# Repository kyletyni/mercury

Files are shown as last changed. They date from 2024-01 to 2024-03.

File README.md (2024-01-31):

This is a custom PCB and software design I created to compete in the APEC Micromouse 
competition in 2024. The design is based on the ESP32-S3 which is a dual core 
microprocessor. The pcb design was done in Kicad 7.0 and the MCU was programmed using 
the esp-idf utilizing RTOS for time dsensitive task scheduling.

Here is a link to an earlier hardware design running in a maze setting with 
control software:
<a href="https://www.youtube.com/watch?v=heloENtCQyA" target="_blank">Demo Video Link</a>

mouse demo (https://www.youtube.com/watch?v=heloENtCQyA)

The PCB schematic consists of IR emitters and receivers, power modules, the MCU, 
gyro, encoders, and buttons.
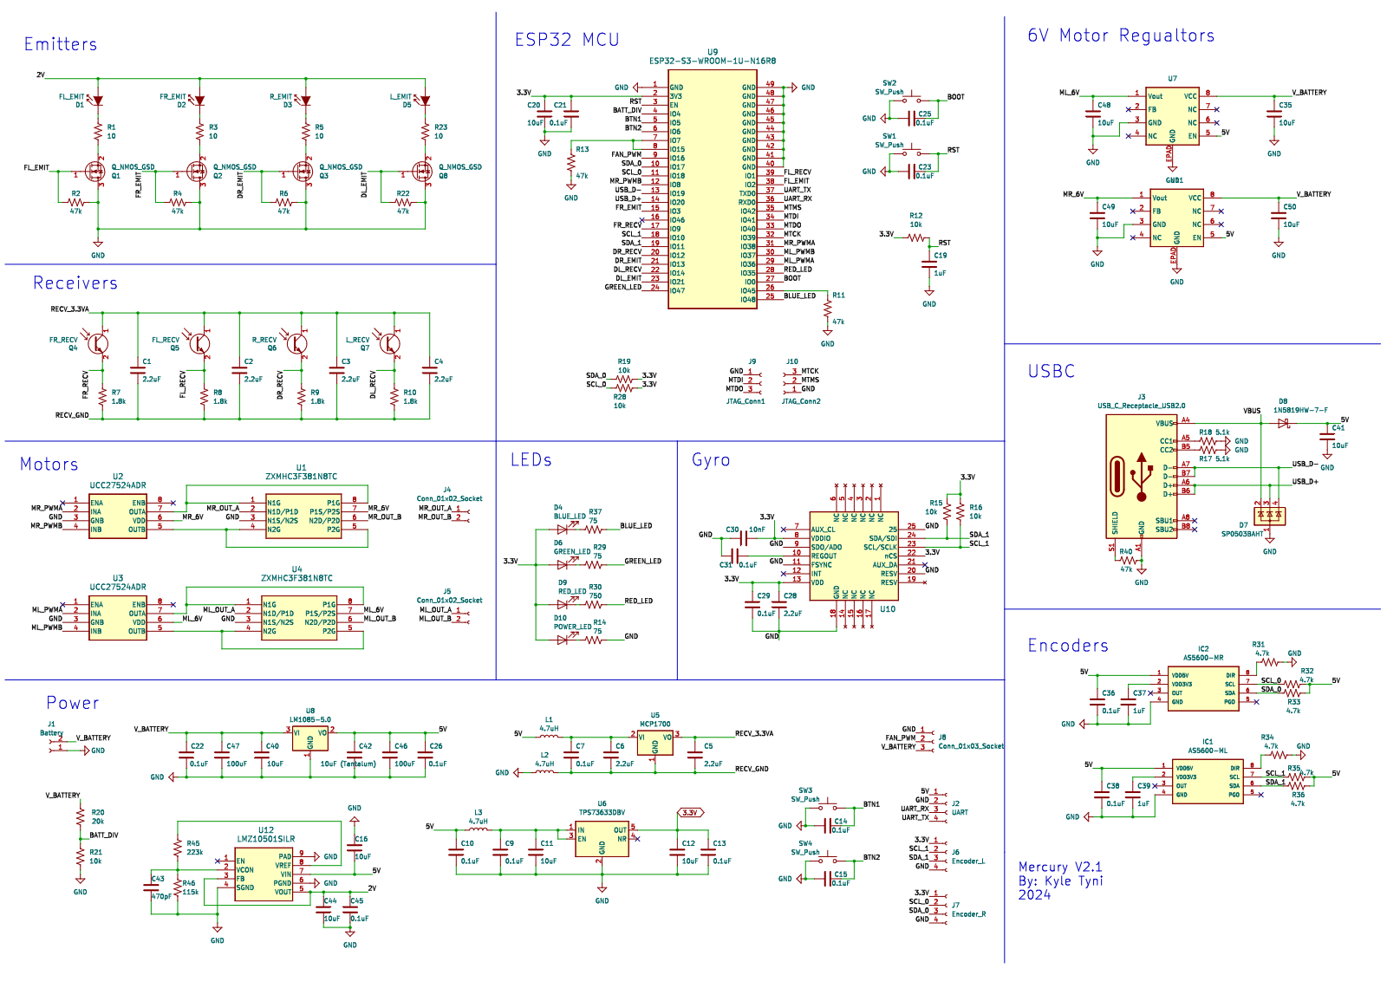
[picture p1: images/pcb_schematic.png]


This is what the PCB looked like when it was delivered.
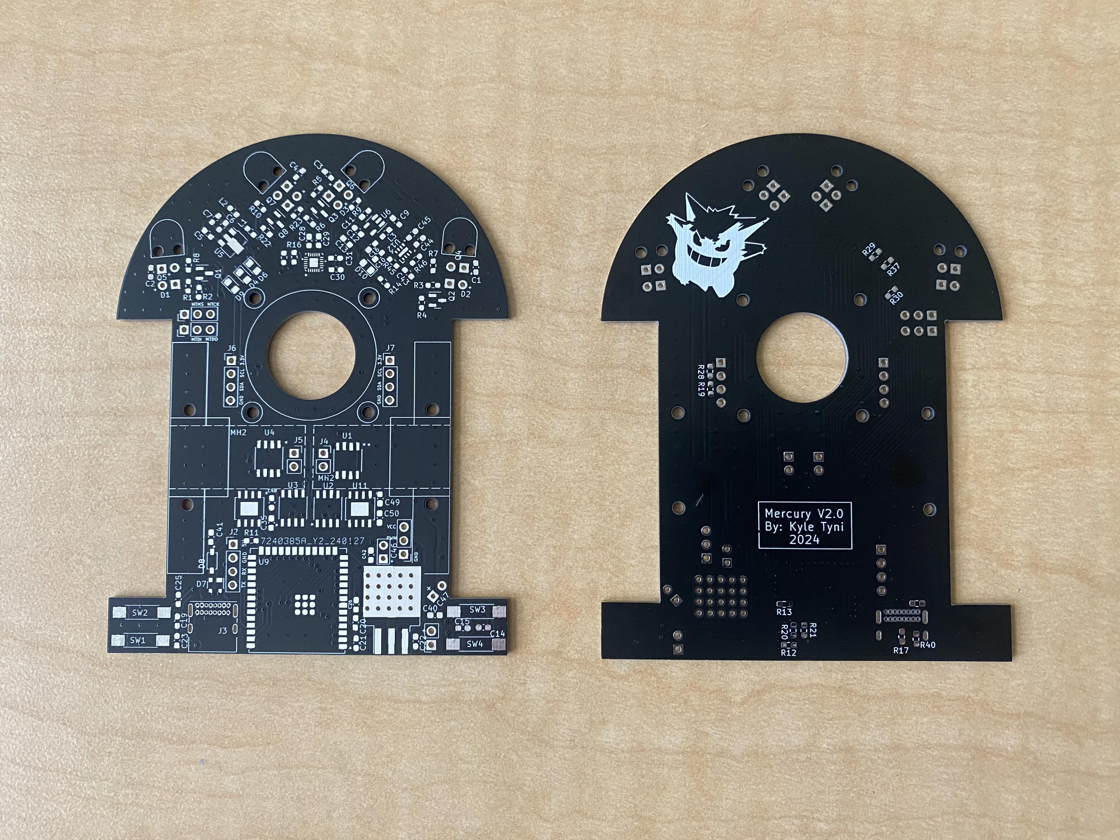
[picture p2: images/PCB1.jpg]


Assembly complete! Software is still a work in progress, but all modules on the board
function individually as expected.

<div style="display:flex; justify-content:space-between;">
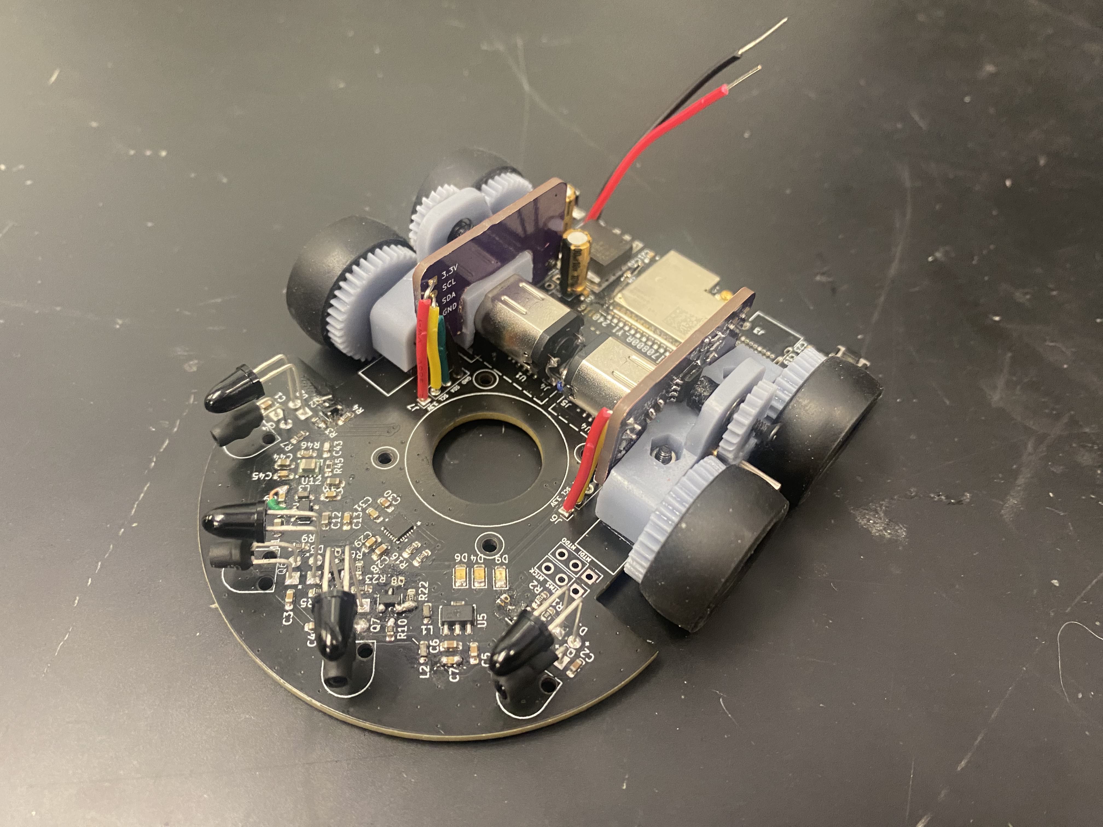
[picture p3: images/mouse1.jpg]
  
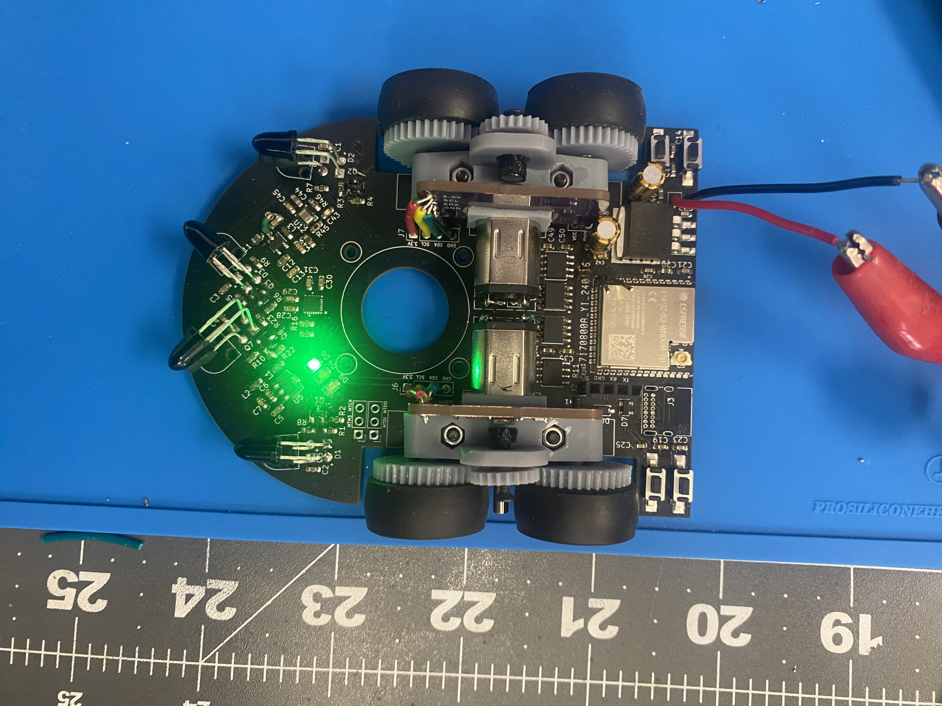
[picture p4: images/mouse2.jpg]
  
</div>

Layout of front and back layers of the board.
<div style="display:flex; justify-content:space-between;">
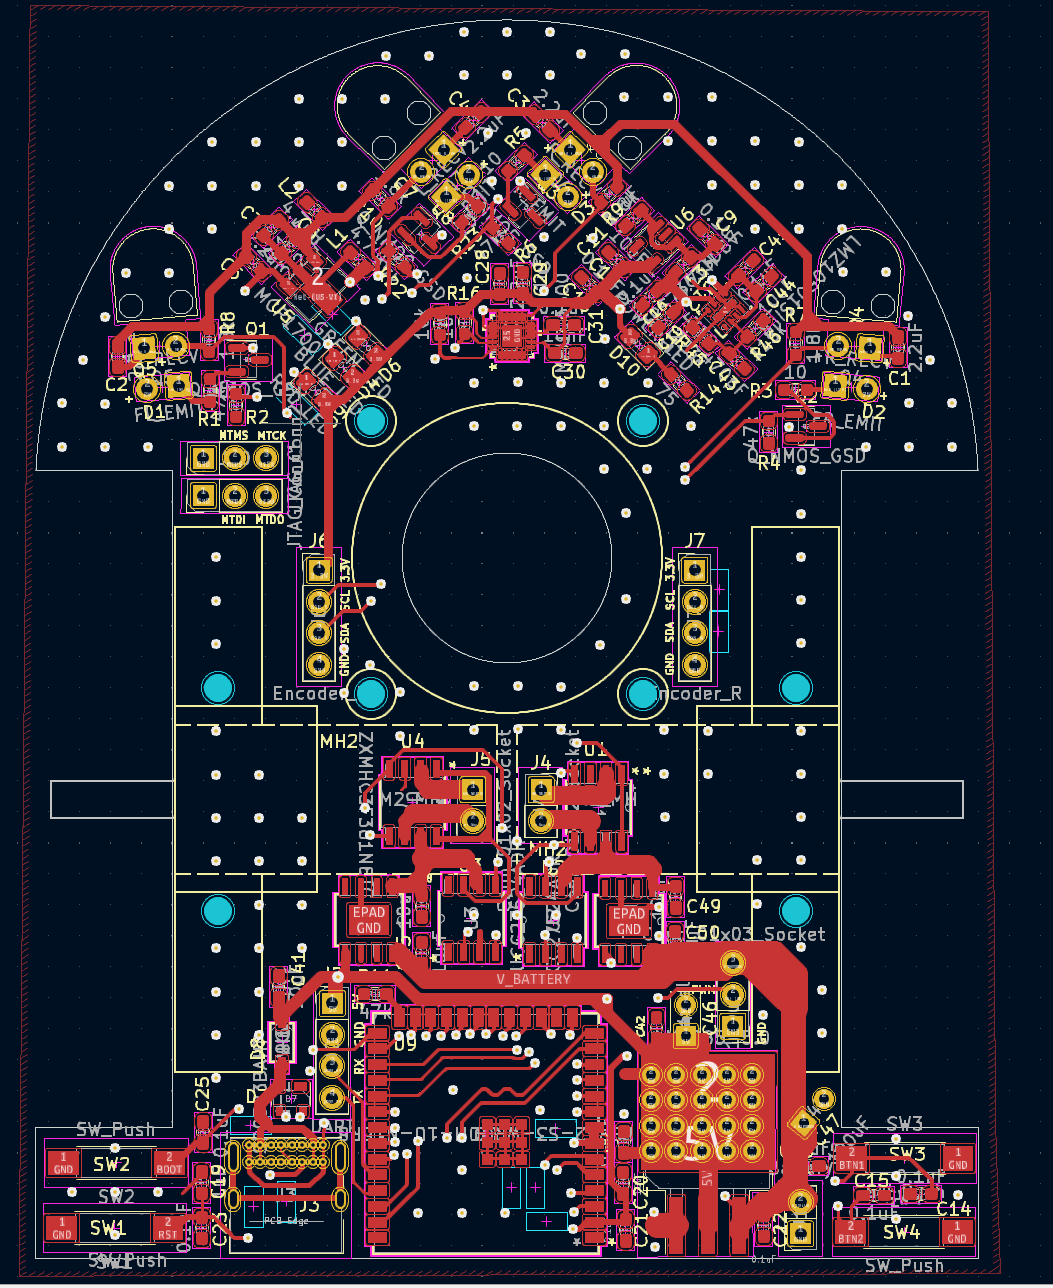
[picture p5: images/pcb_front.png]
  
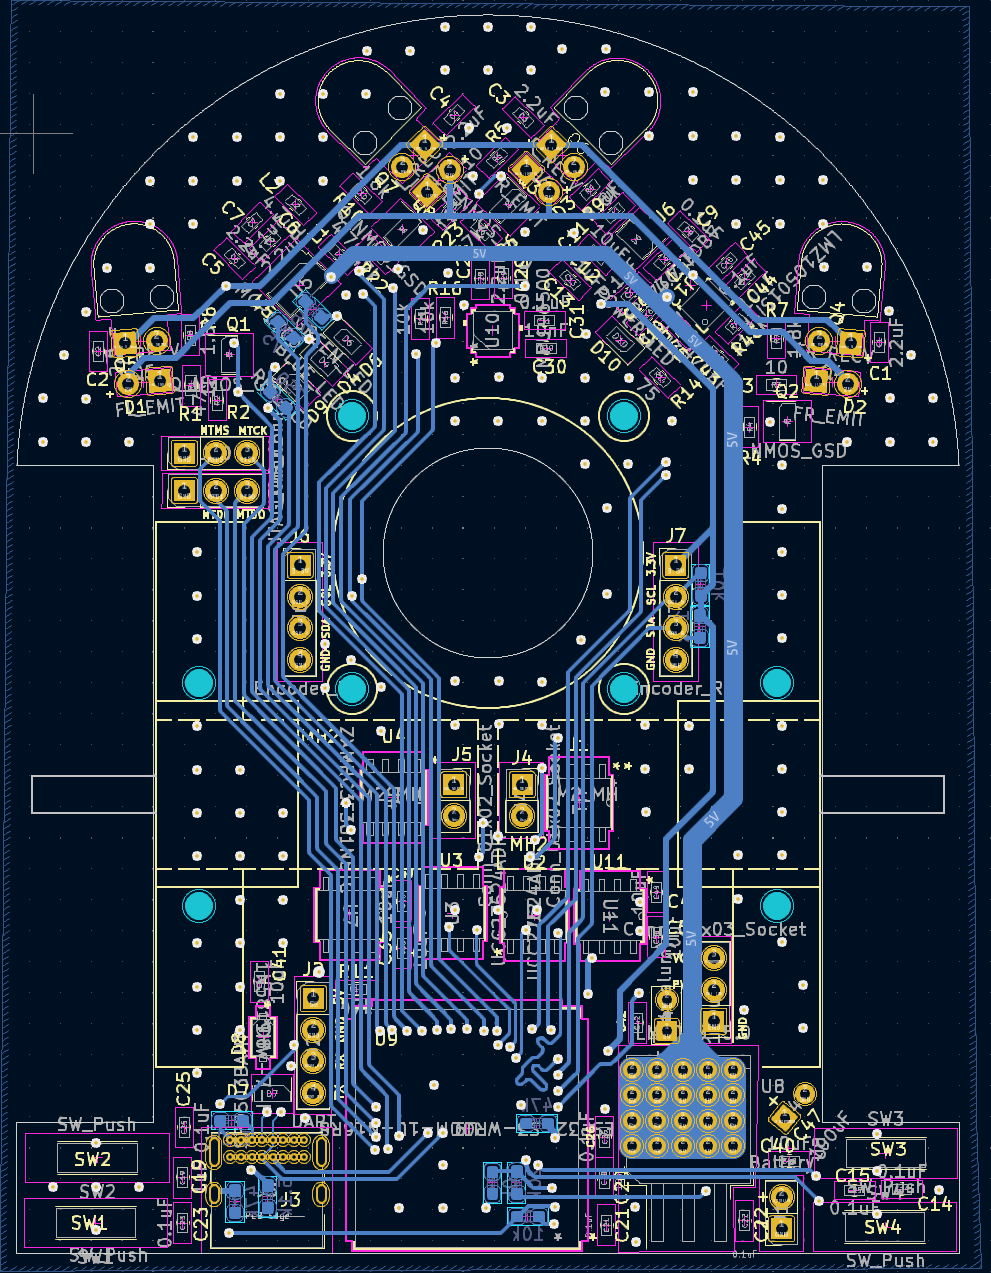
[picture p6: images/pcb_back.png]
  
</div>

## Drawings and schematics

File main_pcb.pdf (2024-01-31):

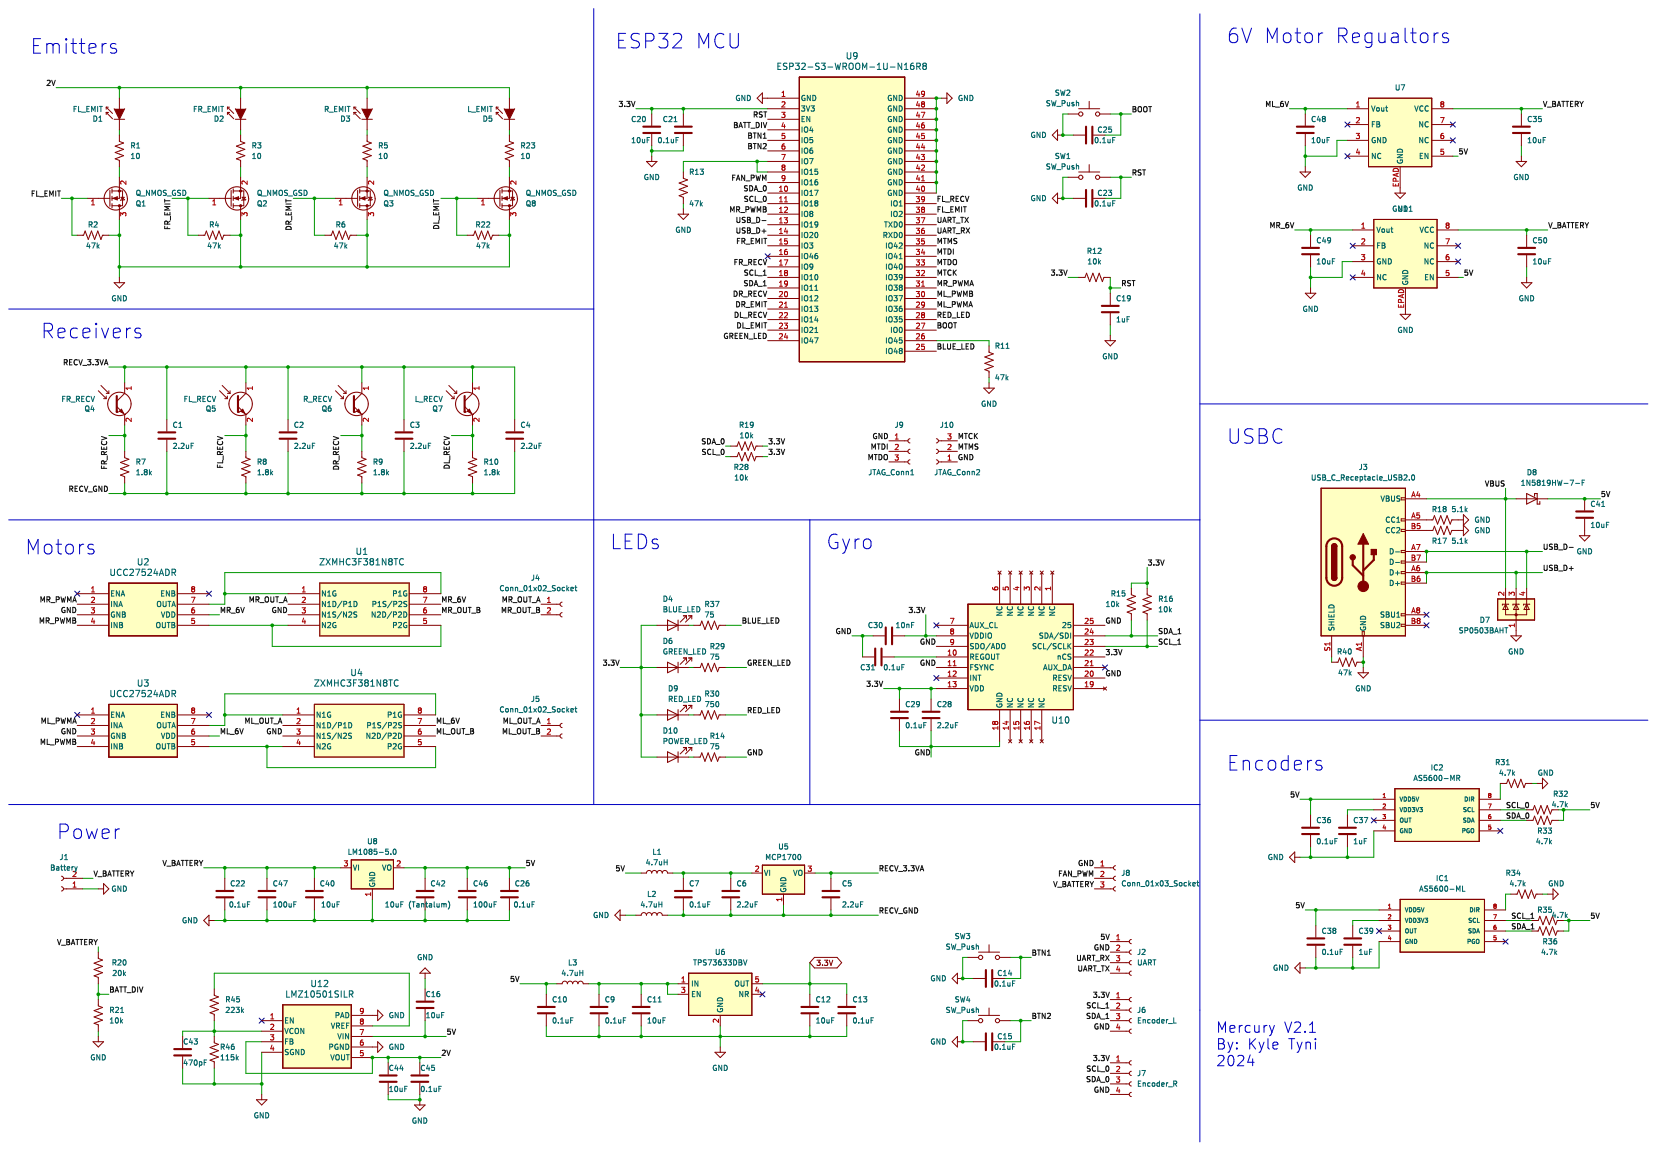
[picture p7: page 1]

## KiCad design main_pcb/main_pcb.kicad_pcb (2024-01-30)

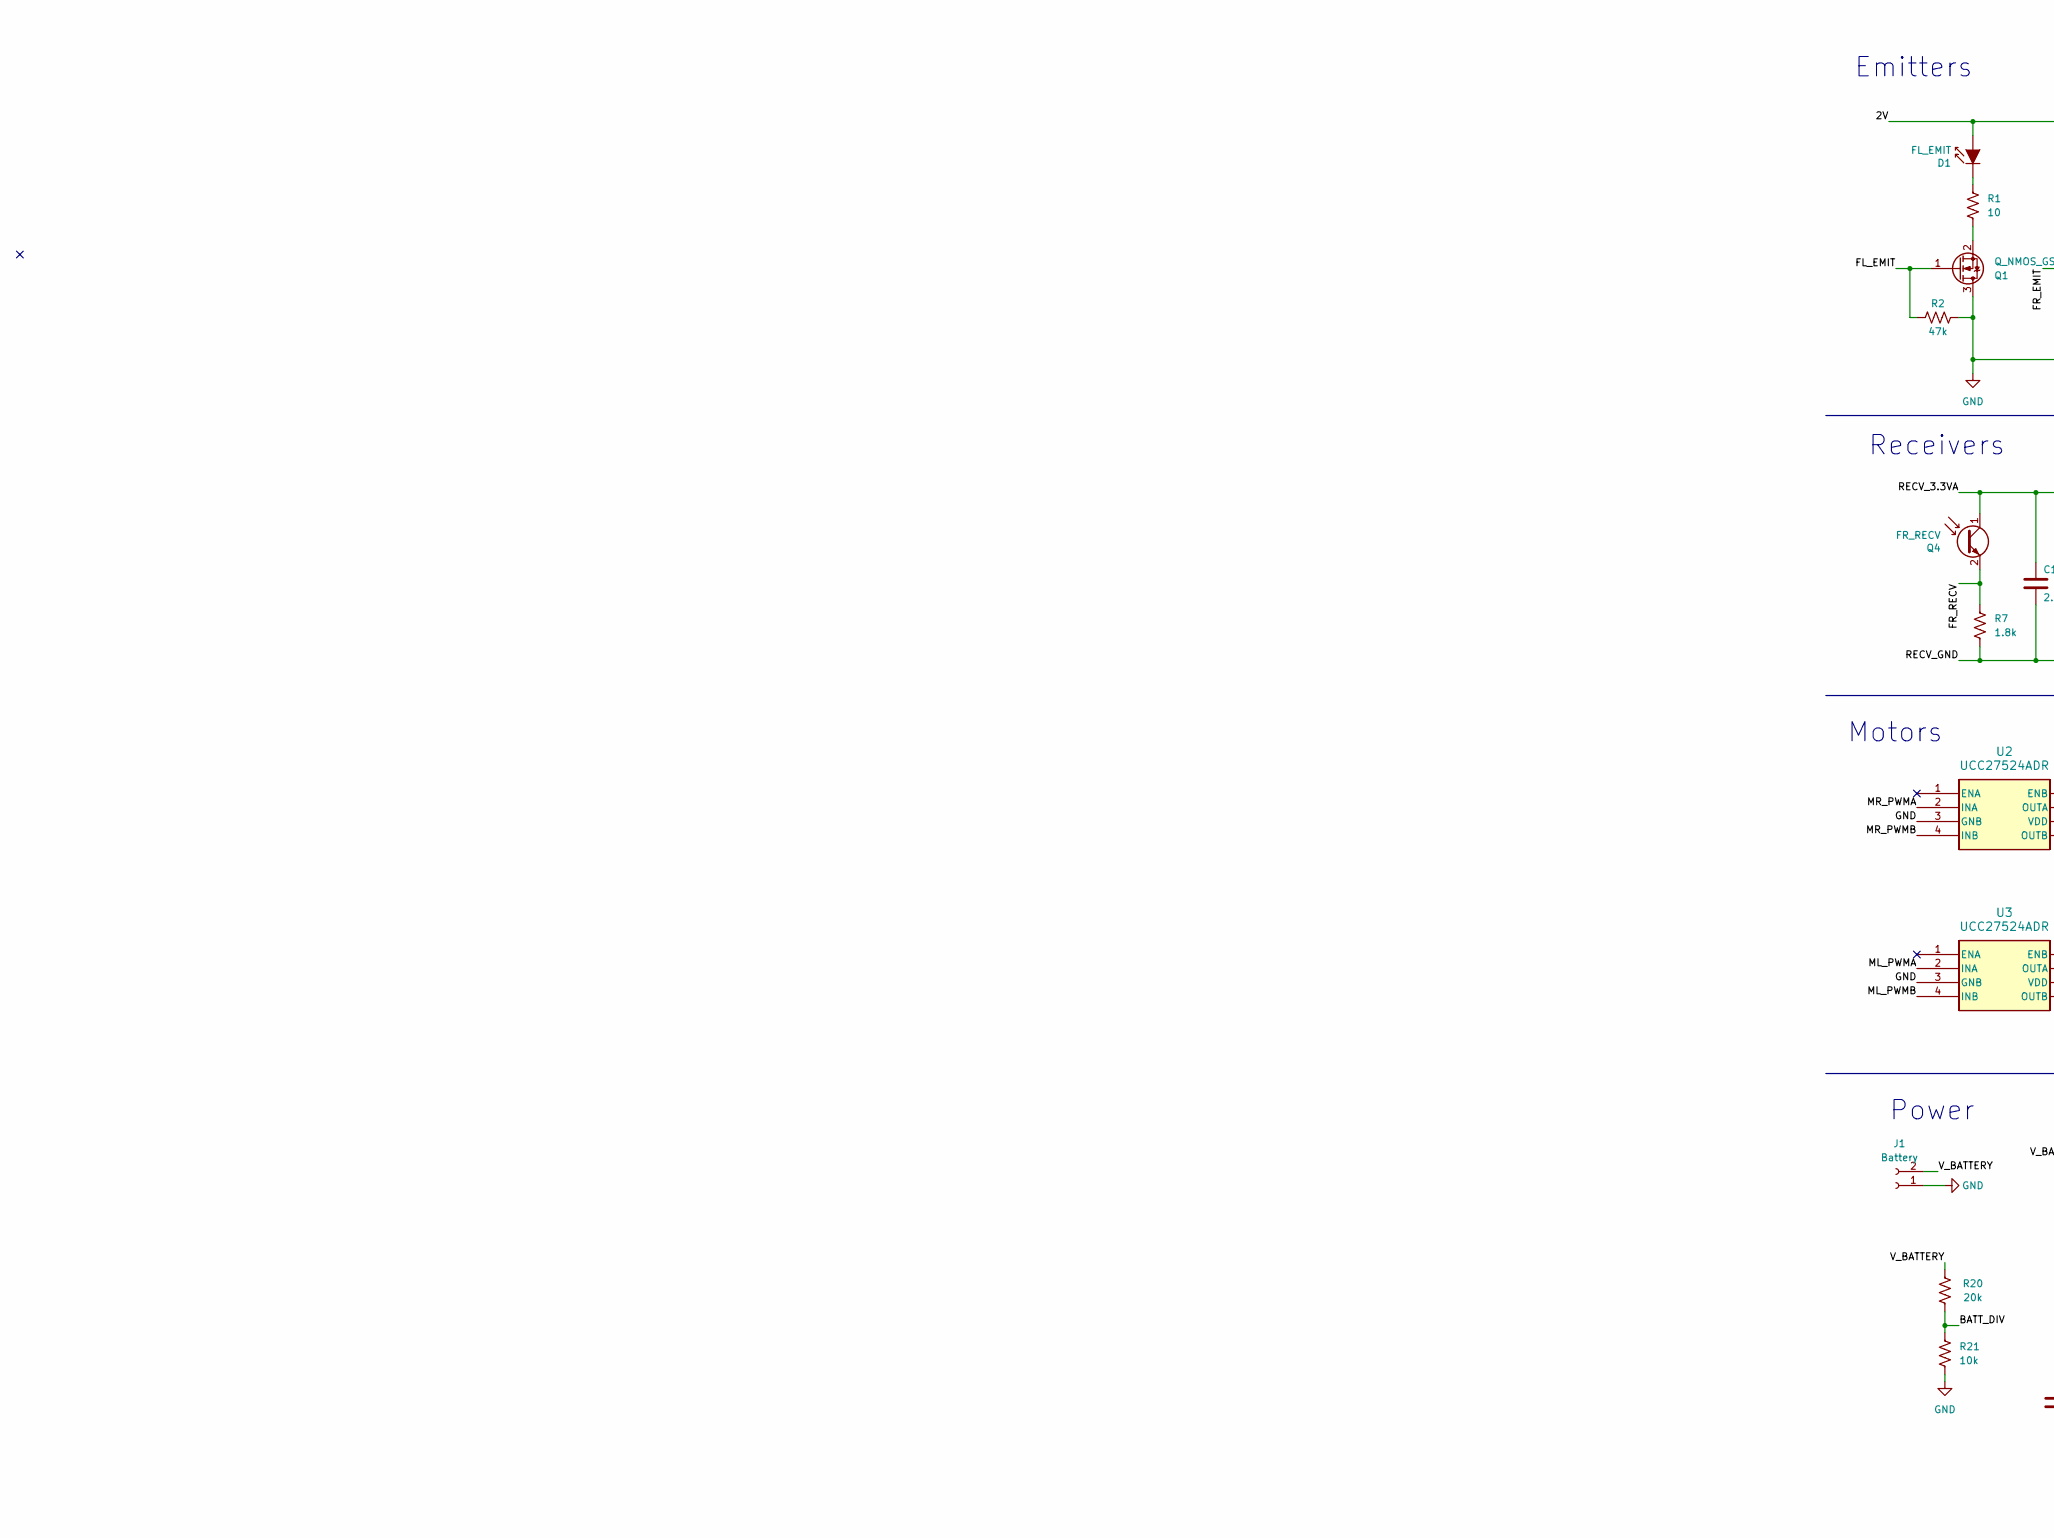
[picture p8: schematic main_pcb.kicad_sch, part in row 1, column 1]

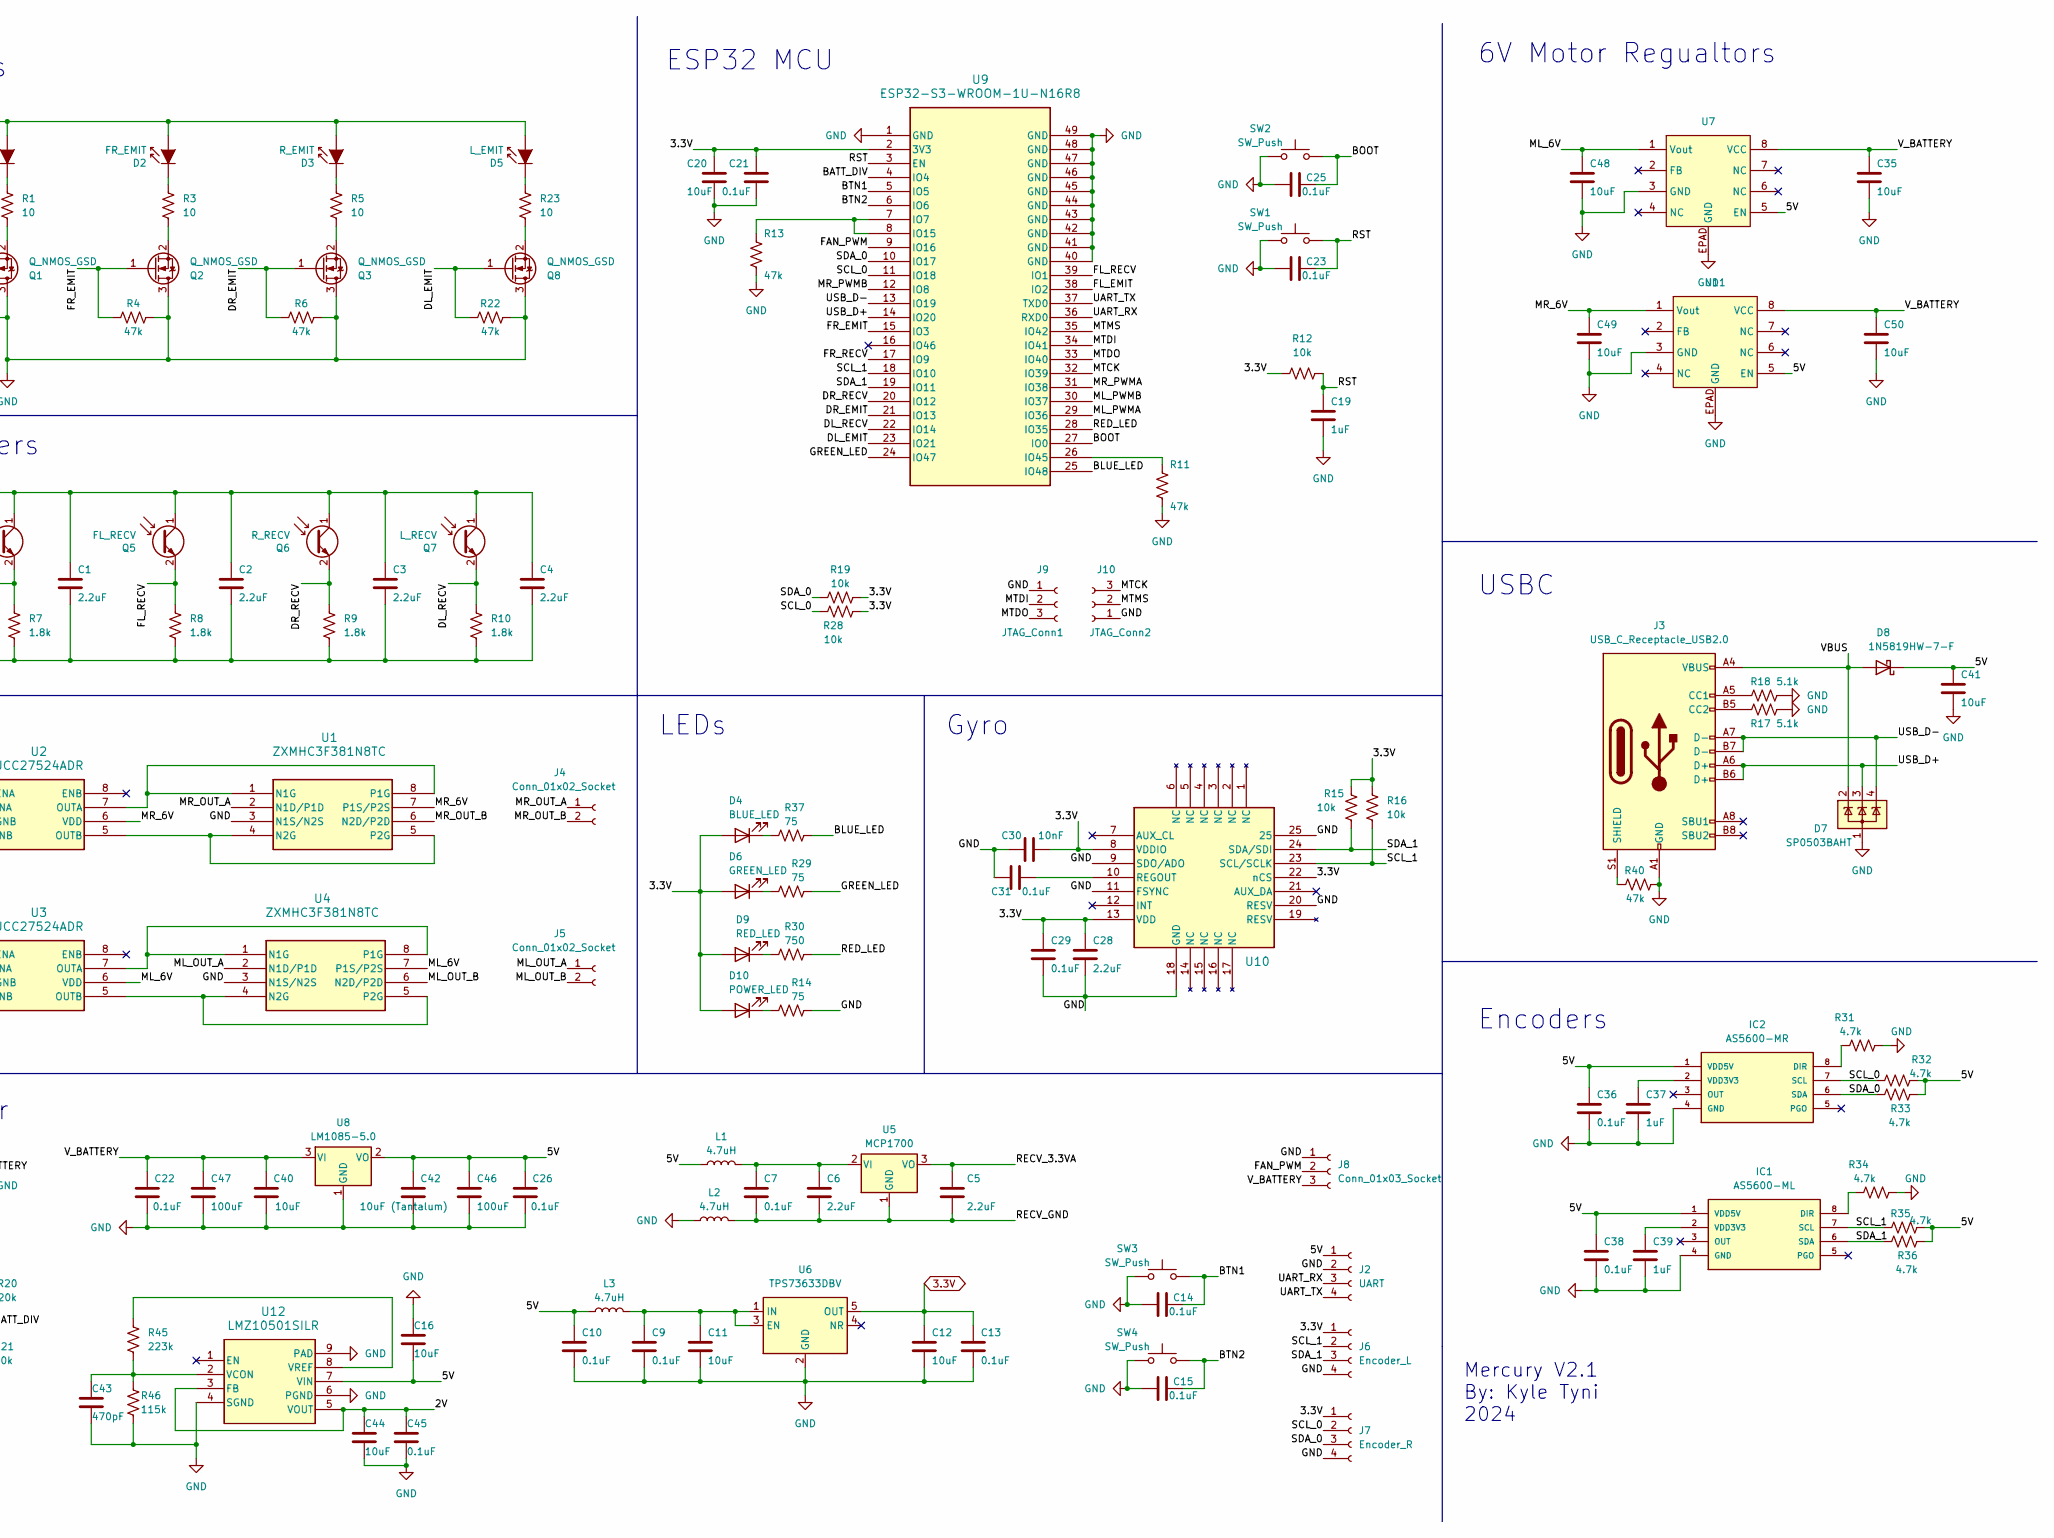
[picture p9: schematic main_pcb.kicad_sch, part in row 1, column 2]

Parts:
C1, C2, C3, C4, C5, C6, C28: 2.2uF; C_0603_1608Metric_Pad1.08x0.95mm_HandSolder
C7, C9, C10, C13, C14, C15, C21, C22, C23, C25, C26, C29, C31, C36, C38, C45: 0.1uF; C_0603_1608Metric_Pad1.08x0.95mm_HandSolder
C11, C12, C16, C20, C35, C40, C41, C44, C48, C49, C50: 10uF; C_0603_1608Metric_Pad1.08x0.95mm_HandSolder
C19, C37, C39: 1uF; C_0603_1608Metric_Pad1.08x0.95mm_HandSolder
C30: 10nF; C_0603_1608Metric_Pad1.08x0.95mm_HandSolder
C42: 10uF (Tantalum); C_0603_1608Metric_Pad1.08x0.95mm_HandSolder
C43: 470pF; C_0603_1608Metric_Pad1.08x0.95mm_HandSolder
C46, C47: 100uF; CP_Radial_D5.0mm_P2.50mm
D1: FL_EMIT; Emitter
D2: FR_EMIT; Emitter
D3: R_EMIT; Emitter
D4: BLUE_LED; LED_0805_2012Metric_Pad1.15x1.40mm_HandSolder
D5: L_EMIT; Emitter
D6: GREEN_LED; LED_0805_2012Metric_Pad1.15x1.40mm_HandSolder
D7: SP0503BAHT; SOT-143
D8: 1N5819HW-7-F; 1N5819HW-7-F_DIO
D9: RED_LED; LED_0805_2012Metric_Pad1.15x1.40mm_HandSolder
D10: POWER_LED; LED_0805_2012Metric_Pad1.15x1.40mm_HandSolder
IC1: AS5600-ML; SOIC127P600X175-8N; MOUSER_PART_NUMBER 985-AS5600-ASOT
IC2: AS5600-MR; SOIC127P600X175-8N; MOUSER_PART_NUMBER 985-AS5600-ASOT
J1: Battery; PinSocket_1x02_P2.54mm_Vertical
J2: UART; PinHeader_1x04_P2.54mm_Vertical
J3: USB_C_Receptacle_USB2.0; USB_C_Receptacle_GCT_USB4085
J4, J5: Conn_01x02_Socket; PinSocket_1x02_P2.54mm_Vertical
J6: Encoder_L; PinHeader_1x04_P2.54mm_Vertical
J7: Encoder_R; PinHeader_1x04_P2.54mm_Vertical
J8: Conn_01x03_Socket; PinHeader_1x03_P2.54mm_Vertical
J9: JTAG_Conn1; PinHeader_1x03_P2.54mm_Vertical
J10: JTAG_Conn2; PinHeader_1x03_P2.54mm_Vertical
L1, L2, L3: 4.7uH; L_0603_1608Metric_Pad1.05x0.95mm_HandSolder
Q1, Q2, Q3, Q8: Q_NMOS_GSD; SOT-23
Q4: FR_RECV; IR_Reciever
Q5: FL_RECV; IR_Receiver_Mirrored
Q6: R_RECV; IR_Receiver_Mirrored
Q7: L_RECV; IR_Reciever
R1, R3, R5, R23: 10; R_0603_1608Metric_Pad0.98x0.95mm_HandSolder
R2, R4, R6, R11, R13, R22, R40: 47k; R_0603_1608Metric_Pad0.98x0.95mm_HandSolder
R7, R8, R9, R10: 1.8k; R_0603_1608Metric_Pad0.98x0.95mm_HandSolder
R12, R15, R16, R19, R21, R28: 10k; R_0603_1608Metric_Pad0.98x0.95mm_HandSolder
R14, R29, R37: 75; R_0603_1608Metric_Pad0.98x0.95mm_HandSolder
R17, R18: 5.1k; R_0603_1608Metric_Pad0.98x0.95mm_HandSolder
R20: 20k; R_0603_1608Metric_Pad0.98x0.95mm_HandSolder
R30: 750; R_0603_1608Metric_Pad0.98x0.95mm_HandSolder
R31, R32, R33, R34, R35, R36: 4.7k; R_0603_1608Metric_Pad0.98x0.95mm_HandSolder
R45: 223k; R_0603_1608Metric_Pad0.98x0.95mm_HandSolder
R46: 115k; R_0603_1608Metric_Pad0.98x0.95mm_HandSolder
SW1, SW2, SW3, SW4: SW_Push; SW_SPST_REED_CT05-XXXX-G1
U1, U4: ZXMHC3F381N8TC; SOIC_81N8TC_DIO
U2, U3: UCC27524ADR; D8_TEX
U5: MCP1700; SOT-89-3
U6: TPS73633DBV; SOT-23-5
U7, U11: HTSOP-J8_ROM
U8: LM1085-5.0; 5V Voltage Reg
U9: ESP32-S3-WROOM-1U-N16R8; ESP32­S3­WROOM­1U_EXP
U10: MPU-6500; QFN24_3X3X0P9_IVS
U12: LMZ10501SILR; SIL0008A

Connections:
3.3V: C12.1, C13.1, C20.1, C21.1, C28.1, C29.1, C30.2, D4.2 (A), D6.2 (A), D9.2 (A), D10.2 (A), J6.1, J7.1, R12.1, R15.1, R16.1, R19.2, R28.2, U6.5 (OUT), U9.2 (3V3), U10.8 (VDDIO), U10.13 (VDD), U10.22 (nCS)
/2V: C44.1, C45.1, D1.2 (A), D2.2 (A), D3.2 (A), D5.2 (A), U12.3 (FB), U12.5 (VOUT)
/5V: C10.1, C16.2, C26.2, C36.1, C38.1, C41.1, C42.2, C46.1, D8.1 (K), IC1.1 (VDD5V), IC2.1 (VDD5V), J2.1, L1.1, L3.1, R32.2, R33.2, R35.2, R36.2, U7.5 (EN), U8.2 (VO), U11.5 (EN), U12.7 (VIN)
/BATT_DIV: R20.1, R21.1, U9.4 (IO4)
/BLUE_LED: R37.2, U9.25 (IO48)
/BOOT: C25.1, SW2.2, U9.27 (IO0)
/BTN1: C14.1, SW3.2, U9.5 (IO5)
/BTN2: C15.1, SW4.2, U9.6 (IO6)
/DL_EMIT: Q8.1 (G), R22.1, U9.23 (IO21)
/DL_RECV: Q7.2 (E), R10.1, U9.22 (IO14)
/DR_EMIT: Q3.1 (G), R6.1, U9.21 (IO13)
/DR_RECV: Q6.2 (E), R9.1, U9.20 (IO12)
/FAN_PWM: J8.2, U9.9 (IO16)
/FL_EMIT: Q1.1 (G), R2.1, U9.38 (IO2)
/FL_RECV: Q5.2 (E), R8.1, U9.39 (IO1)
/FR_EMIT: Q2.1 (G), R4.1, U9.15 (IO3)
/FR_RECV: Q4.2 (E), R7.1, U9.17 (IO9)
/GREEN_LED: R29.2, U9.24 (IO47)
/ML_6V: C48.1, U3.6 (VDD), U4.7 (P1S/P2S), U7.1 (Vout)
/ML_OUT_A: J5.1, U4.2 (N1D/P1D)
/ML_OUT_B: J5.2, U4.6 (N2D/P2D)
/ML_PWMA: U3.2 (INA), U9.29 (IO36)
/ML_PWMB: U3.4 (INB), U9.30 (IO37)
/MR_6V: C49.1, U1.7 (P1S/P2S), U2.6 (VDD), U11.1 (Vout)
/MR_OUT_A: J4.1, U1.2 (N1D/P1D)
/MR_OUT_B: J4.2, U1.6 (N2D/P2D)
/MR_PWMA: U2.2 (INA), U9.31 (IO38)
/MR_PWMB: U2.4 (INB), U9.12 (IO8)
/MTCK: J10.3, U9.32 (IO39)
/MTDI: J9.2, U9.34 (IO41)
/MTDO: J9.3, U9.33 (IO40)
/MTMS: J10.2, U9.35 (IO42)
/RECV_3.3VA: C1.1, C2.1, C3.1, C4.1, C5.1, Q4.1 (C), Q5.1 (C), Q6.1 (C), Q7.1 (C), U5.3 (VO)
/RECV_GND: C1.2, C2.2, C3.2, C4.2, C5.2, C6.2, C7.2, L2.2, R7.2, R8.2, R9.2, R10.2, U5.1 (GND)
/RED_LED: R30.2, U9.28 (IO35)
/RST: C19.1, C23.1, R12.2, SW1.2, U9.3 (EN)
/SCL_0: IC2.7 (SCL), J7.2, R28.1, R32.1, U9.11 (IO18)
/SCL_1: IC1.7 (SCL), J6.2, R16.2, R35.1, U9.18 (IO10), U10.23 (SCL/SCLK)
/SDA_0: IC2.6 (SDA), J7.3, R19.1, R33.1, U9.10 (IO17)
/SDA_1: IC1.6 (SDA), J6.3, R15.2, R36.1, U9.19 (IO11), U10.24 (SDA/SDI)
/UART_RX: J2.3, U9.36 (RXD0)
/UART_TX: J2.4, U9.37 (TXD0)
/USB_D+: D7.3 (K), J3.A6 (D+), J3.B6 (D+), U9.14 (IO20)
/USB_D-: D7.4 (K), J3.A7 (D-), J3.B7 (D-), U9.13 (IO19)
/VBUS: D7.2 (K), D8.2 (A), J3.A4 (VBUS), J3.A9 (VBUS), J3.B4 (VBUS), J3.B9 (VBUS)
/V_BATTERY: C22.2, C35.1, C40.2, C47.1, C50.1, J1.2, J8.3, R20.2, U7.8 (VCC), U8.3 (VI), U11.8 (VCC)
GND: C9.2, C10.2, C11.2, C12.2, C13.2, C14.2, C15.2, C16.1, C19.2, C20.2, C21.2, C22.1, C23.2, C25.2, C26.1, C28.2, C29.2, C30.1, C31.1, C35.2, C36.2, C37.2, C38.2, C39.2, C40.1, C41.2, C42.1, C43.2, C44.2, C45.2, C46.2, C47.2, C48.2, C49.2, C50.2, D7.1 (A), IC1.4 (GND), IC2.4 (GND), J1.1, J2.2, J3.A1 (GND), J3.A12 (GND), J3.B1 (GND), J3.B12 (GND), J6.4, J7.4, J8.1, J9.1, J10.1, L2.1, Q1.3 (D), Q2.3 (D), Q3.3 (D), Q8.3 (D), R2.2, R4.2, R6.2, R11.1, R13.1, R14.2, R17.2, R18.2, R21.2, R22.2, R31.2, R34.2, R40.2, R46.2, SW1.1, SW2.1, SW3.1, SW4.1, U1.3 (N1S/N2S), U2.3 (GNB), U3.3 (GNB), U4.3 (N1S/N2S), U6.2 (GND), U7.3 (GND), U7.EPAD (GND), U8.1 (GND), U9.1 (GND), U9.40 (GND), U9.41 (GND), U9.42 (GND), U9.43 (GND), U9.44 (GND), U9.45 (GND), U9.46 (GND), U9.47 (GND), U9.48 (GND), U9.49 (GND), U10.9 (SDO/ADO), U10.11 (FSYNC), U10.18 (GND), U10.20 (RESV), U10.25, U11.3 (GND), U11.EPAD (GND), U12.4 (SGND), U12.6 (PGND), U12.9 (PAD)
unnamed: C37.1, IC2.2 (VDD3V3)
unnamed: C39.1, IC1.2 (VDD3V3)
unnamed: D1.1 (K), R1.1
unnamed: D2.1 (K), R3.1
unnamed: D3.1 (K), R5.1
unnamed: D4.1 (K), R37.1
unnamed: D5.1 (K), R23.1
unnamed: D6.1 (K), R29.1
unnamed: D9.1 (K), R30.1
unnamed: D10.1 (K), R14.1
unnamed: IC1.8 (DIR), R34.1
unnamed: IC2.8 (DIR), R31.1
unnamed: J3.A5 (CC1), R18.1
unnamed: J3.B5 (CC2), R17.1
unnamed: J3.S1 (SHIELD), R40.1
unnamed: Q1.2 (S), R1.2
unnamed: Q2.2 (S), R3.2
unnamed: Q3.2 (S), R5.2
unnamed: Q8.2 (S), R23.2
unnamed: U1.1 (N1G), U1.8 (P1G), U2.7 (OUTA)
unnamed: U1.4 (N2G), U1.5 (P2G), U2.5 (OUTB)
unnamed: U3.7 (OUTA), U4.1 (N1G), U4.8 (P1G)
unnamed: U3.5 (OUTB), U4.4 (N2G), U4.5 (P2G)
unnamed: C6.1, C7.1, L1.2, U5.2 (VI)
unnamed: C9.1, C11.1, L3.2, U6.1 (IN), U6.3 (EN)
unnamed: R13.2, U9.7 (IO7), U9.8 (IO15)
unnamed: R11.2, U9.26 (IO45)
unnamed: C31.2, U10.10 (REGOUT)
unnamed: C43.1, R45.2, R46.1, U12.2 (VCON)
unnamed: R45.1, U12.8 (VREF)

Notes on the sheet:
USBC
LEDs
Power
6V Motor Regualtors
Encoders
Emitters
Motors
Mercury V2.1 By: Kyle Tyni 2024
Gyro
ESP32 MCU
Receivers

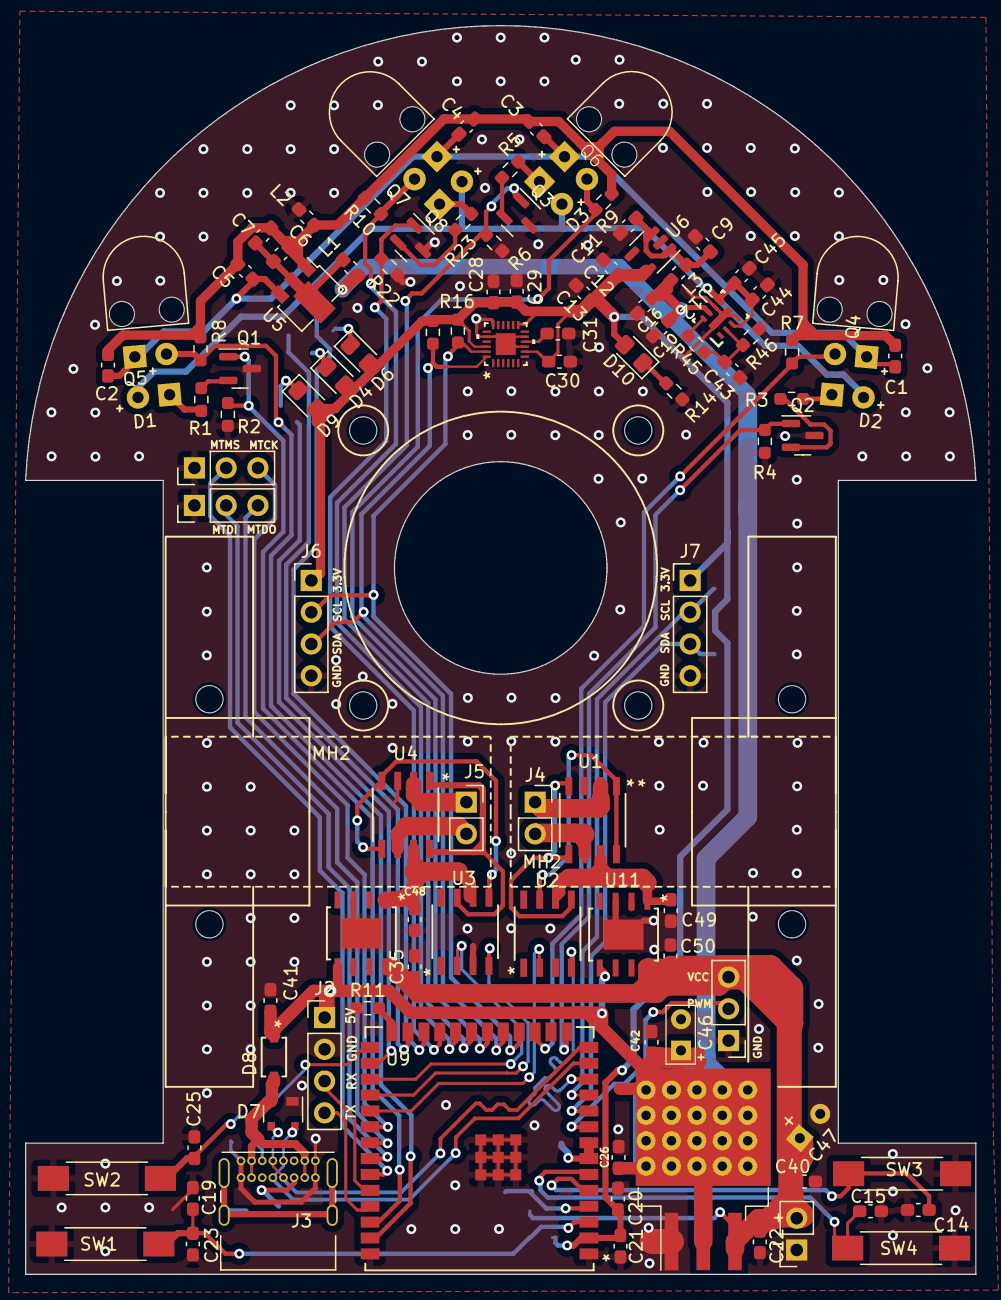
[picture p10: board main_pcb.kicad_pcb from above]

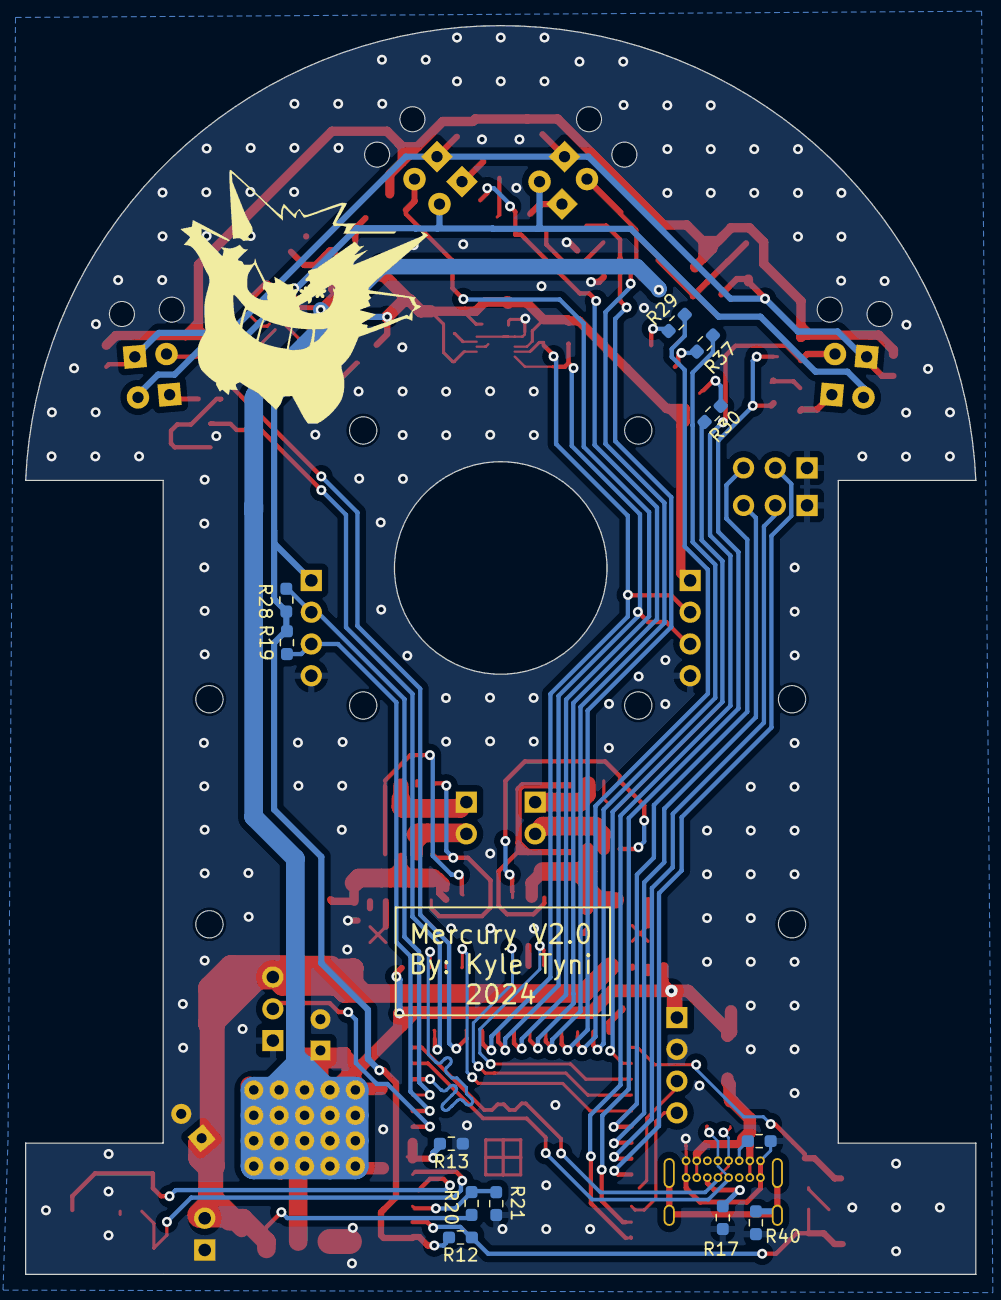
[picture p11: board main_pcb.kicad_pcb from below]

Board: 2 copper layers, 76.0 x 99.9 mm, 117 parts (12 on the bottom side), 73 nets.

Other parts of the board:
MH2, MH2#2: M2_MH; Motor

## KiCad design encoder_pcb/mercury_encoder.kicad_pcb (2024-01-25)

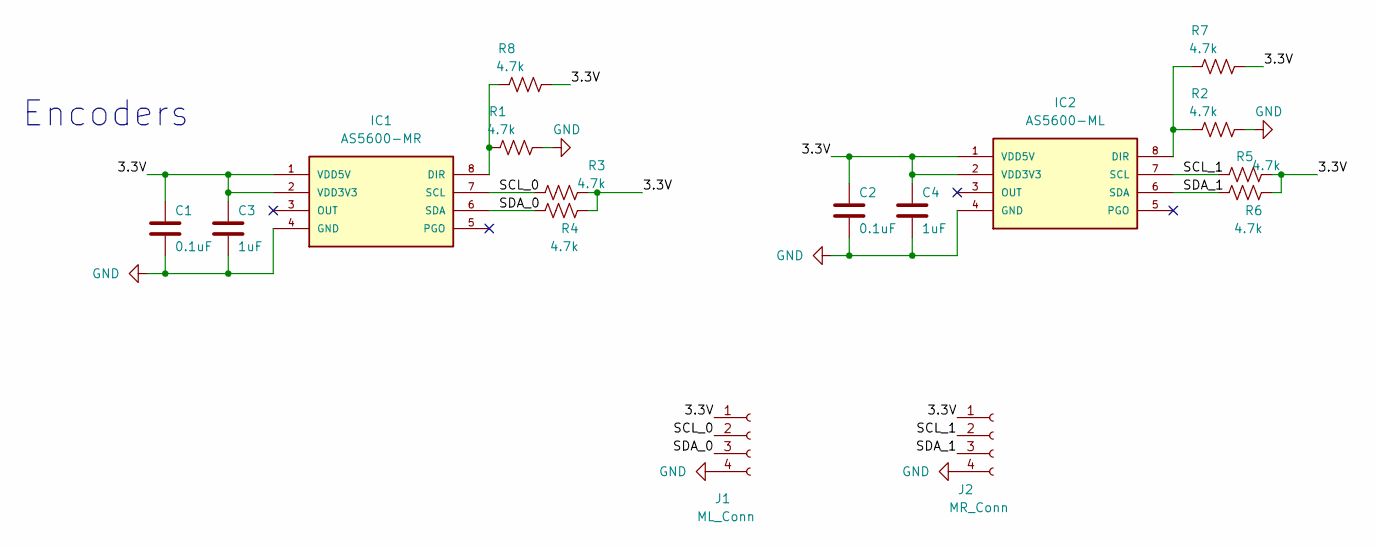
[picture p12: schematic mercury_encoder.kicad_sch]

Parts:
C1, C2: 0.1uF; C_0603_1608Metric_Pad1.08x0.95mm_HandSolder
C3, C4: 1uF; C_0603_1608Metric_Pad1.08x0.95mm_HandSolder
IC1: AS5600-MR; SOIC127P600X175-8N; MOUSER_PART_NUMBER 985-AS5600-ASOT
IC2: AS5600-ML; SOIC127P600X175-8N; MOUSER_PART_NUMBER 985-AS5600-ASOT
J1: ML_Conn; PinSocket_1x04_P2.54mm_Vertical
J2: MR_Conn; PinSocket_1x04_P2.54mm_Vertical
R1, R2, R3, R4, R5, R6, R7, R8: 4.7k; R_0603_1608Metric_Pad0.98x0.95mm_HandSolder

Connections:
/3.3V: C1.1, C2.1, C3.1, C4.1, IC1.1 (VDD5V), IC1.2 (VDD3V3), IC2.1 (VDD5V), IC2.2 (VDD3V3), J1.1, J2.1, R3.2, R4.2, R5.2, R6.2, R7.2, R8.2
/SCL_0: IC1.7 (SCL), J1.2, R3.1
/SCL_1: IC2.7 (SCL), J2.2, R5.1
/SDA_0: IC1.6 (SDA), J1.3, R4.1
/SDA_1: IC2.6 (SDA), J2.3, R6.1
GND: C1.2, C2.2, C3.2, C4.2, IC1.4 (GND), IC2.4 (GND), J1.4, J2.4, R1.2, R2.2
unnamed: IC1.8 (DIR), R1.1, R8.1
unnamed: IC2.8 (DIR), R2.1, R7.1

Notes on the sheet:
Encoders

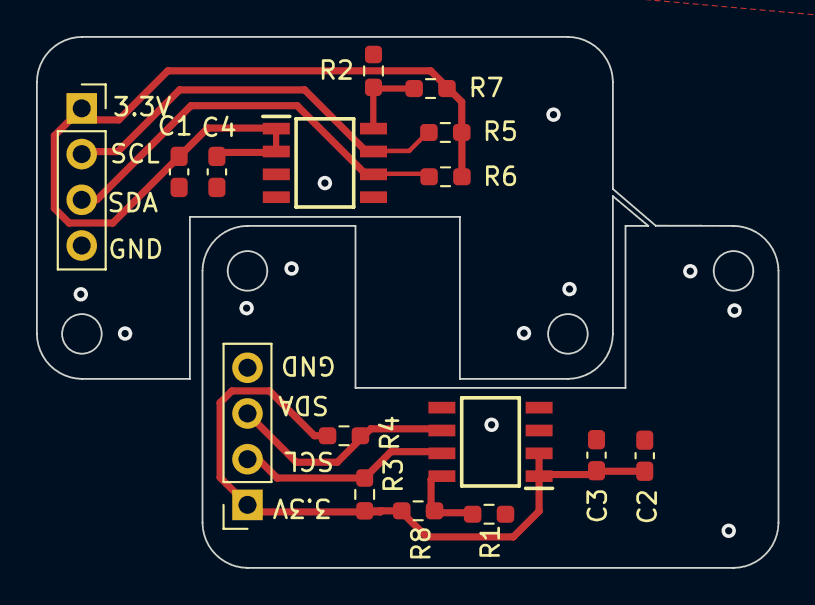
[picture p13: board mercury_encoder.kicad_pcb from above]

Board: 2 copper layers, 41.2 x 29.5 mm, 16 parts (0 on the bottom side), 8 nets.

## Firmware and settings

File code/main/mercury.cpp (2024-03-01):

#include <stdio.h>

#include <sdkconfig.h>
#include <freertos/FreeRTOS.h>
#include <freertos/task.h>
#include <freertos/portmacro.h>
#include <freertos/queue.h>
#include <esp_system.h>
#include <esp_task_wdt.h>

#include "esp_log.h"
#include "driver/i2c.h"
#include "driver/gpio.h"
#include "encoder.h"
#include "emitter.h"
#include "profile.h"
#include "motors.h"
#include "receiver.h"
#include "maze.h"
#include "user.h"
#include "gyro.h"
#include "config.h"
#include "motion.h"

#define BLUE_LED GPIO_NUM_48
#define GREEN_LED GPIO_NUM_47
#define RED_LED GPIO_NUM_35

const char *TAG = "main";

void sensorPollTask(void *pvParameters);
void motorControlTask(void *pvParameters);
void operatorTask(void *pvParameters);

MessageBufferHandle_t xMessageBufferToClient;
QueueHandle_t xQueueTrans;


extern "C" void app_main(void)
{
    // esp_set_cpu_affinity(xTaskGetCurrentTask(), esp_cpu_pin_to_core(CPU_0)); // Core 0 for current task
    // vPortSetTickFrequency(1000);

    ESP_ERROR_CHECK(i2c_master_init());
    ESP_LOGI(TAG, "I2C initialized successfully");

    init_emit_pin(EMIT_DR);
    init_emit_pin(EMIT_DL);
    init_emit_pin(EMIT_FR);
    init_emit_pin(EMIT_FL);
    ESP_LOGI(TAG, "EMIT pins initialized successfully");

    init_user_io();
    ESP_LOGI(TAG, "LED pins initialized successfully");

    init_uart();
    //ESP_LOGI(TAG, "UART initialized successfully");
    
    initialize_adc();
    ESP_LOGI(TAG, "ADC initialized successfully");
    
    init_motors();
    ESP_LOGI(TAG, "Motor PWM initialized successfully");
    

    // xTaskCreate(&button_task, "button_task", 4096, NULL, 10, NULL);

    ESP_LOGI(TAG, "Spawning Tasks for Core 0");
    // xTaskCreatePinnedToCore(&mpu6500, "gyroTask", 4096, NULL, 1, NULL, 0);
    xTaskCreatePinnedToCore(sensorPollTask, "sensorPollTask", 4096, NULL, 2, NULL, 0);

    ESP_LOGI(TAG, "Creating Tasks for Core 1");
    xTaskCreatePinnedToCore(motorControlTask, "motorControlTask", 4096, NULL, 2, NULL, 1);
    xTaskCreatePinnedToCore(operatorTask, "operatorTask", 4096, NULL, 1, NULL, 1);
}


void sensorPollTask(void *pvParameters)
{
    TickType_t xFrequency = pdMS_TO_TICKS(1); // convert to ms
    TickType_t xLastWakeTime;
    xLastWakeTime = xTaskGetTickCount();

    reset_encoder_count();
    int count = 0;

    while (true)
    {   
        xLastWakeTime = xTaskGetTickCount();
        /******************* Continuously Poll Encoder Counts *******************/
        update_encoders();
        update_distances();

        // NOTE: RIGHT Encoder Counts DOWN when dir is FORWARD, counts UP when dir is BACKWARD
        // NOTE: LEFT Encoder Counts UP when dir is FORWARD, counts DOWN when dir is BACKWARD
        
        /******************* Continuously Poll IR Sensors *******************/
        ir_sensor_poll(FRONT_LEFT);
        ir_sensor_poll(DIAGONAL_LEFT);
        ir_sensor_poll(DIAGONAL_RIGHT);
        ir_sensor_poll(FRONT_RIGHT);
        
        // calculate cross track error
        calc_cross_track_error();

        // if no walls, we should use gyro

        if (count % 40 == 0) {
            // if(!Profile_Is_Finished(&forward)) {
                // ESP_LOGI(TAG, "DL: %4d, DR: %4d, POS: %.2f", recv_avg_val[DIAGONAL_LEFT], recv_avg_val[DIAGONAL_RIGHT], forward.position    );
            // }
            // ESP_LOGI(TAG, "FR: %4d, DR: %4d, DL: %4d, FL: %4d, FRONT: %.2f, DE: %.2f", recv_avg_val[FRONT_RIGHT], recv_avg_val[DIAGONAL_RIGHT], recv_avg_val[DIAGONAL_LEFT], recv_avg_val[FRONT_LEFT], front_sensor_sum, front_dist_error);
            // ESP_LOGI(TAG, "FR: %.2f, DR: %.2f, DL: %.2f, FL: %.2f, FRONT: %.2f", rec_adc_raw_sum[FRONT_RIGHT], rec_adc_raw_sum[DIAGONAL_RIGHT], rec_adc_raw_sum[DIAGONAL_LEFT], rec_adc_raw_sum[FRONT_LEFT], front_sensor_sum);
            // ESP_LOGI(TAG, "FR: %4d, DR: %4d, DL: %4d, FL: %4d, FRONT: %.2f", recv_adc_raw[FRONT_RIGHT], recv_adc_raw[DIAGONAL_RIGHT], recv_adc_raw[DIAGONAL_LEFT], recv_adc_raw[FRONT_LEFT], front_sensor_sum);

            count = 1;
        } else {
            count++;
        }

        vTaskDelayUntil(&xLastWakeTime, xFrequency);
        TickType_t xElapsedTime = (xTaskGetTickCount() - xLastWakeTime);
        if (xElapsedTime > xFrequency) {
            ESP_LOGW(TAG, "WARNING: 'sensorPollTask' exceeded deadline: %ld ms!", xElapsedTime);
        }
    }
}


void motorControlTask(void *pvParameters)
{
    TickType_t xFrequency = pdMS_TO_TICKS(2); // convert to ms
    TickType_t xLastWakeTime;
    xLastWakeTime = xTaskGetTickCount();

    float fwd_output;
    float rot_output;

    float left_output_v;
    float right_output_v;

    mouse_distance = 0.f;
    Profile_Reset(&forward);
    Profile_Reset(&rotation);

    int count = 0;
    controller_output_enabled = true;
    steering_enabled = false;

    while (true)
    {
        xLastWakeTime = xTaskGetTickCount();
        
        // Updates Profiles
        Profile_Update(&forward);
        Profile_Update(&rotation);


        if (steering_mode == SM_FRONT_BASED) {
            fwd_output = front_dist_controller();
        } else {
            fwd_output = forward_controller();
        }

        // calculate rotational adjustment
        static float rot_adjust = 0.f;

        if (steering_enabled) {
            if (steering_mode == SM_SIDE_BASED) {
                rot_adjust = (STEERING_KP * cross_track_error) + (STEERING_KD * cross_track_error - cross_track_error_prev);
            } else {
                rot_adjust = (FRONT_STEERING_KP * front_align_error);

            }
            rot_adjust *= LOOP_INTERVAL;
            if (rot_adjust < -STEERING_ADJUSTMENT_LIMIT)
                rot_adjust = -STEERING_ADJUSTMENT_LIMIT;
            else if (rot_adjust > STEERING_ADJUSTMENT_LIMIT)
                rot_adjust = STEERING_ADJUSTMENT_LIMIT;
        } else {
            rot_adjust = 0.f;
        }

        rot_output = rotation_controller(rot_adjust);
        left_output_v = fwd_output + rot_output;
        right_output_v = fwd_output - rot_output;

        float tangent_velocity = rotation.velocity * MOUSE_RADIUS * RADIANS_PER_DEGREE;
        float left_speed = forward.velocity + tangent_velocity;
        float right_speed = forward.velocity - tangent_velocity;

        float left_ff = left_ff_voltage(left_speed);
        float right_ff = right_ff_voltage(right_speed);

        // print logic
        if (count % 40 == 0) {
            count = 1;
            // ESP_LOGI(TAG, "f_err %.2f f %.2f", front_dist_error, front_sensor_sum);
            // ESP_LOGI(TAG, "a %.2f r %.2f g %.2f", mouse_angle, rotation.position, mouse_yaw);
            // ESP_LOGI(TAG, "a %.2f y %.2f, R: %d, F: %d, L: %d", rot_adjust, rot_output, right_wall_present, front_wall_present, left_wall_present);
        }
        else {
            count++;
        }

        // Output motor voltages
        left_output_v += left_ff;
        right_output_v += right_ff;
        
        if (controller_output_enabled) {
            set_motor_voltage(MOTOR_RIGHT, right_output_v);
            set_motor_voltage(MOTOR_LEFT, left_output_v);
        }

        vTaskDelayUntil(&xLastWakeTime, xFrequency);
        TickType_t xElapsedTime = (xTaskGetTickCount() - xLastWakeTime);
        if (xElapsedTime > xFrequency) {
            ESP_LOGW(TAG, "WARNING: 'motorControlTask' exceeded deadline: %ld ms!", xElapsedTime);
        }
    }
}

void operatorTask(void *pvParameters)
{
    TickType_t xFrequency = pdMS_TO_TICKS(1); // convert to ms
    TickType_t xLastWakeTime = xTaskGetTickCount();

    bool test_fwd = true;

    // while (!gyro_init) {
    //     vTaskDelay(2);
    // }

    user_select_mode = SEARCH_MODE_SELECT;

    maze.m_mask = MASK_OPEN;
    reset_maze(&maze);
    flood(&maze);
    maze.m_mouse_heading = NORTH;
    maze.m_mouse_pos = (Pos){0, 0};
    Heading bestHeading = NORTH;

    while (true) 
    {
        if (user_active_mode == SELECT_MODE_ACTIVE) {
            gpio_set_level(RED_LED, 1);


            if (gpio_get_level(BTN2) == 0) {
                user_select_mode = (UserSelectMode)((user_select_mode + 1) % SELECT_MENU_SIZE);
                vTaskDelay(100 / portTICK_PERIOD_MS);
            }

            if (gpio_get_level(BTN1) == 0) {
                user_active_mode = (UserActiveMode)((user_active_mode + 1) % ACTIVE_MODE_SIZE);
                vTaskDelay(100 / portTICK_PERIOD_MS);
                continue;
            }

            switch (user_select_mode)
            {
                case SEARCH_MODE_SELECT:
                    gpio_set_level(GREEN_LED, 0);
                    gpio_set_level(BLUE_LED, 1);
                    break;
                case SPEED_MODE_SELECT:
                    gpio_set_level(GREEN_LED, 1);
                    gpio_set_level(BLUE_LED, 0);
                    break;
                default:
                    break;
            }
        } else {
            gpio_set_level(RED_LED, 0);
            
            if (gpio_get_level(BTN1) == 0) {
                user_active_mode = (UserActiveMode)((user_active_mode + 1) % ACTIVE_MODE_SIZE);
                vTaskDelay(200 / portTICK_PERIOD_MS);
                continue;
            }

            // check for arming based on front right and diag right sensor vals
            if (recv_avg_val[DIAGONAL_RIGHT] > 150 && recv_avg_val[FRONT_RIGHT] > 250)
            {
                ESP_LOGI(TAG, "armed and starting");
                while(true)
                {
                    gpio_set_level(RED_LED, 1);
                    gpio_set_level(BLUE_LED, 1);
                    gpio_set_level(GREEN_LED, 1);

                    if (user_select_mode == SEARCH_MODE_SELECT) {
                        ESP_LOGI(TAG, "starting search");
                        vTaskDelay(2000);

                        // while (true)
                        // {
                        //     if (left_wall_present) {
                        //         gpio_set_level(RED_LED, 0);
                        //     } else {
                        //         gpio_set_level(RED_LED, 1);
                        //     }

                        //     if (right_wall_present) {
                        //         gpio_set_level(GREEN_LED, 0);
                        //     } else {
                        //         gpio_set_level(GREEN_LED, 1);
                        //     }

                        //     if (front_wall_present) {
                        //         gpio_set_level(BLUE_LED, 0);
                        //     } else {
                        //         gpio_set_level(BLUE_LED, 1);
                        //     }
                        //   vTaskDelay(2);
                        // }

                        // align_with_front_wall();
                        maze.m_mask = MASK_OPEN;
                        search((Pos){7, 7}, true);

                        // print_maze_state(&maze);

                        vTaskDelay(1000);

                        maze.m_goal = (Pos){0, 0};
                        flood(&maze);
                        Heading bestHeading = heading_to_smallest(&maze, maze.m_mouse_pos, maze.m_mouse_heading);
                        uint8_t headingChange = ((bestHeading - maze.m_mouse_heading) >> 1) & 0x3;
                        maze.m_mouse_heading = bestHeading;

                        
                        // print_maze_state(&maze);

                        switch (headingChange) {
                            case RIGHT:
                                turn_IP(90.f, 287.f, 2850.f);
                                break;

                            case LEFT:
                                turn_IP(-90.f, 287.f, 2850.f);
                                break;

                            case BACK:
                                turn_IP(180.f, 287.f, 2850.f);
                                break;

                            default:
                                break;
                        }
                        search((Pos){0, 0}, false);


                        maze.m_mouse_pos = (Pos){0, 0};
                        maze.m_mouse_heading = NORTH;
                        user_active_mode = SELECT_MODE_ACTIVE;
                        break;
                    } else if (user_select_mode == SPEED_MODE_SELECT) {
                        // speed mode, must perform search before utilizing this mode
                        gpio_set_level(RED_LED, 1);
                        gpio_set_level(BLUE_LED, 1);
                        gpio_set_level(GREEN_LED, 1);

                        ESP_LOGI(TAG, "starting search");
                        vTaskDelay(2000);

                        // align_with_front_wall();
                        maze.m_mask = MASK_OPEN;
                        basic_search((Pos){7, 7}, true);

                        print_maze_state(&maze);
                        vTaskDelay(1000);

                        maze.m_goal = (Pos){0, 0};
                        flood(&maze);
                        Heading bestHeading = heading_to_smallest(&maze, maze.m_mouse_pos, maze.m_mouse_heading);
                        uint8_t headingChange = ((bestHeading - maze.m_mouse_heading) >> 1) & 0x3;
                        maze.m_mouse_heading = bestHeading;

                        
                        // print_maze_state(&maze);

                        switch (headingChange) {
                            case RIGHT:
                                turn_IP(90.f, 287.f, 2850.f);
                                break;

                            case LEFT:
                                turn_IP(-90.f, 287.f, 2850.f);
                                break;

                            case BACK:
                                turn_IP(180.f, 287.f, 2850.f);
                                break;

                            default:
                                break;
                        }
                        search((Pos){0, 0}, false);


                        maze.m_mouse_pos = (Pos){0, 0};
                        maze.m_mouse_heading = NORTH;
                        user_active_mode = SELECT_MODE_ACTIVE;
                        break;
                    }
                        

                        // ESP_LOGI(TAG, "starting speed");
                        // maze.m_mask = MASK_CLOSED;

                        // int num_moves = generate_speed_moves((Pos){7, 7});
                        // float end_speed = 0.f;
                        
                        // Profile_Start(&forward, -HALF_CELL, SEARCH_VELOCITY / 4, 0.f, SEARCH_ACCELERATION / 3);
                        // while(!Profile_Is_Finished(&forward)) { vTaskDelay(1); }
                        // vTaskDelay(200);

                        // for(uint8_t i = 0; i < num_moves; i++)
                        // {
                        //     // check next movement for end speed
                        //     if (i + 1 < num_moves) {
                        //         if (speed_movements[i + 1].type != SS_FWD) {
                        //             end_speed = SEARCH_TURN_SPEED;   
                        //         }
                        //     }

                        //     if (speed_movements[i].type == SS_FWD)
                        //     {
                        //         if (i == 0) {
                        //             move_forward(speed_movements[i].num * FULL_CELL - BACK_TO_CENTER_DIST, SPEED_VELOCITY, SEARCH_TURN_SPEED, SPEED_ACCELERATION);
                        //         } else {
                        //             move_forward(speed_movements[i].num * FULL_CELL, SPEED_VELOCITY, SEARCH_TURN_SPEED, SPEED_ACCELERATION);
                        //         }
                        //     } else if (speed_movements[i].type == SS90EL) {
                        //         for (uint8_t j = 0; j < speed_movements[i].num; j++) {
                        //             turn_smooth(SS90EL);
                        //         }
                        //     } else if (speed_movements[i].type == SS90ER) {
                        //         for (uint8_t j = 0; j < speed_movements[i].num; j++) {
                        //             turn_smooth(SS90ER);
                        //         }
                        //     } else {
                        //         // shouldn't get here
                        //     }
                        // }

                        // stop_at_center();
                    
                    // vTaskDelay(1500);

                    // search((Pos){0, 0}, false);

                    vTaskDelay(2);
                    // break;
                }
            }
        }

        vTaskDelay(100 / portTICK_PERIOD_MS);

        // search((Pos){0, 2}, true);
        // vTaskDelay(300);
        // search((Pos){0, 0}, false);


    }
}

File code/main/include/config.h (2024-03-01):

#ifndef CONFIG_H
#define CONFIG_H

#define PI_VAL 3.1415f
#define MERCURY_CFG

#define APEC_CONFIG

#ifdef MERCURY_CFG

    #define ROTATION_BIAS 0
    #define WHEEL_DIAMETER 22.8f //22.6f
    #define ENCODER_COUNTS_PER_REV 4096
    #define GEAR_RATIO (38.f / 22.f)
    #define FF_VOLTAGE 0.00193f
    #define BIAS_VOLTAGE 0.47f // might have to set higher

    #define FWD_TIME_CONST 0.15f
    #define ROT_TM 0.1f
    #define FF_ACC_VOLTAGE (FWD_TIME_CONST * FF_VOLTAGE)

    #define MOUSE_RADIUS 41.5 // 40.5f

    #define FWD_KP 0.25f
    #define FWD_KD 0.02f//0.15f

    #define STEERING_KP 0.3f //0.4f //0.8f
    #define STEERING_KD 0.05f //0.35f

    #define FRONT_STEERING_KP 0.15f

    #define STEERING_ADJUSTMENT_LIMIT 10.f


    #define LOOP_FREQUENCY (500.f)
    #define LOOP_INTERVAL  (1.f / LOOP_FREQUENCY)

    #ifdef APEC_CONFIG
        // RAW values
        #define DIAG_RIGHT_CALIB  230 // 220 
        #define DIAG_LEFT_CALIB   260
        #define FRONT_RIGHT_CALIB 520
        #define FRONT_LEFT_CALIB  370

        // nominal vals
        #define FRONT_LEFT_CALIB_WHEN_CENTERED  620
        #define FRONT_RIGHT_CALIB_WHEN_CENTERED 525
        // front sensor sum to trigger a turn, because the front wall is close enough
        
        // translated to nominal (front sensor sum)
        #define SEARCH_TURN_TRIGGER 300

        #define RIGHT_THRESHOLD 67 // 82 //66 // 72 // 65
        #define LEFT_THRESHOLD  63 //65 // 72 // 65

        #define RIGHT_THRESHOLD_W_FRONT_WALL 85
        #define LEFT_THRESHOLD_W_FRONT_WALL 90

        #define FRONT_THRESHOLD 180 // 115 //135 // 170
        #define FRONT_THRESHOLD_TO_DSIABLE_SIDE_CORRECTION 220
        #define FRONT_THRESHOLD_FOR_HIGHER_SIDE_DETECT 220//175

        // above this value for the front sensor sum, the side sensors become
        // unreliable to do steering
        #define SIDE_RELIABILITY_THRESHOLD 270 
        const float FRONT_REFERENCE = 1200; // 1000;
    #endif

    #ifndef APEC_CONFIG
        #define DIAG_RIGHT_CALIB  295
        #define DIAG_LEFT_CALIB   280
        #define FRONT_RIGHT_CALIB 584
        #define FRONT_LEFT_CALIB  532
        #define FRONT_LEFT_CALIB_WHEN_CENTERED  690
        #define FRONT_RIGHT_CALIB_WHEN_CENTERED 595
        // front sensor sum to trigger a turn, because the front wall is close enough
        #define SEARCH_TURN_TRIGGER 258
    
        #define RIGHT_THRESHOLD 66 // 72 // 65
        #define LEFT_THRESHOLD  66 // 72 // 65
        #define FRONT_THRESHOLD 150 // 170
        
        // front sensor sum when the mouse is centered in the cell
        // its the converted value reading
        const float FRONT_REFERENCE = 900;
    #endif

    #define SIDE_NOMINAL  100.f
    #define FRONT_NOMINAL 200.f


    #define TURN_THRESHOLD 4
    #define EXTRA_WALL_ADJUST 5

    #define FULL_CELL 180.f
    #define HALF_CELL FULL_CELL / 2.f

    #define BACK_TO_CENTER_DIST 37 //53

    #define WALL_TO_ABSENT_VAL 43

    // FULL_CELL - 15mm
    #define SENSING_POS_OFFSET 15.f
    #define SENSING_POS FULL_CELL - SENSING_POS_OFFSET

#endif

const uint16_t SMOOTH_TURN_SPEED = 500;

const float ROT_KM = 347.f;  // deg/s/Volt
const float ROT_ZETA = 0.707;   
const float ROT_TD = ROT_TM;

const float ROT_KP = 0.15f; //0.2f; //16 * ROT_TM / (ROT_KM * ROT_ZETA * ROT_ZETA * ROT_TD * ROT_TD);
const float ROT_KD = 0.04f; //LOOP_FREQUENCY * (8 * ROT_TM - ROT_TD) / (ROT_KM * ROT_TD);

const float MM_PER_ENC_COUNT = PI_VAL * WHEEL_DIAMETER / (ENCODER_COUNTS_PER_REV * GEAR_RATIO);
const float MM_PER_COUNT_LEFT = (1 - ROTATION_BIAS) * MM_PER_ENC_COUNT;
const float MM_PER_COUNT_RIGHT = (1 + ROTATION_BIAS) * MM_PER_ENC_COUNT;
const float DEG_PER_MM_DIFFERENCE = (180.f / (2.f * MOUSE_RADIUS * PI_VAL));
const float RADIANS_PER_DEGREE = 2.f * PI_VAL / 360.f;
const float DEGREES_PER_RADIAN = 360.f / 2.f * PI_VAL;

const float FRONT_LEFT_SCALE = FRONT_NOMINAL / FRONT_LEFT_CALIB;
const float FRONT_RIGHT_SCALE = FRONT_NOMINAL / FRONT_RIGHT_CALIB;
const float DIAG_LEFT_SCALE = SIDE_NOMINAL / DIAG_LEFT_CALIB;
const float DIAG_RIGHT_SCALE = SIDE_NOMINAL / DIAG_RIGHT_CALIB;


const uint16_t SEARCH_VELOCITY = 400;
const uint16_t SEARCH_TURN_VELOCITY = 300;
const uint16_t SEARCH_ACCELERATION = 2000;
const uint16_t SEARCH_TURN_SPEED = 300;

const uint16_t SPEED_VELOCITY = 400;
const uint16_t SPEED_ACCELERATION = 2000;

#endif

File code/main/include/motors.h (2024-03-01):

#ifndef MOTORS_H
#define MOTORS_H

#include <stdbool.h>
#include <stdint.h>
#include "driver/gpio.h"
#include "driver/ledc.h"
#include "profile.h"
#include "receiver.h"
#include "config.h"
#include "gyro.h"

#define MR_PWMA_GPIO GPIO_NUM_38
#define MR_PWMA_CHANNEL LEDC_CHANNEL_0

#define MR_PWMB_GPIO GPIO_NUM_8
#define MR_PWMB_CHANNEL LEDC_CHANNEL_1

#define ML_PWMA_GPIO GPIO_NUM_36
#define ML_PWMA_CHANNEL LEDC_CHANNEL_2

#define ML_PWMB_GPIO GPIO_NUM_37
#define ML_PWMB_CHANNEL LEDC_CHANNEL_3   

#define PWM_FREQUENCY 15000

bool controller_enabled;

float fwd_error;
float fwd_error_prev;

float rot_error;
float rot_error_prev;

typedef enum {
    MOTOR_LEFT = 0,
    MOTOR_RIGHT
} MotorSide;

typedef enum {
    FORWARD = 0,
    BACKWARD
} MotorDir;

MotorDir left_motor_dir_cur;
MotorDir right_motor_dir_cur;
MotorDir left_motor_dir_target;
MotorDir right_motor_dir_target;

float left_motor_voltage;
float right_motor_voltage;

bool controller_output_enabled;
bool steering_enabled = false;

static void set_motor_pwm_dc(ledc_channel_t channel, float duty);
void set_motor_dir(MotorSide side, MotorDir dir);

void init_motors(void) {
    fwd_error = 0.f;
    rot_error = 0.f;
    fwd_error_prev = 0.f;
    rot_error_prev = 0.f;

    ledc_fade_func_install(0);

    // PWM Timer Configuration
    ledc_timer_config_t ledc_timer;
    ledc_timer.speed_mode = LEDC_LOW_SPEED_MODE;      // timer mode
    ledc_timer.duty_resolution = LEDC_TIMER_12_BIT;   // resolution of PWM duty
    ledc_timer.timer_num = LEDC_TIMER_0;             // timer index
    ledc_timer.freq_hz = PWM_FREQUENCY;               // frequency of PWM signal
    ledc_timer.clk_cfg = LEDC_AUTO_CLK;               // Auto select the source clock
    ledc_timer_config(&ledc_timer);

    // PWM Channel Configuration
    ledc_channel_config_t ledc_channel;
    ledc_channel.channel    = LEDC_CHANNEL_0;
    ledc_channel.duty       = 0;
    ledc_channel.gpio_num   = MR_PWMA_GPIO;
    ledc_channel.speed_mode = LEDC_LOW_SPEED_MODE;
    ledc_channel.hpoint     = 0;
    ledc_channel.timer_sel  = LEDC_TIMER_0;
    ledc_channel_config(&ledc_channel);

    set_motor_pwm_dc(MR_PWMA_CHANNEL, 0.f);

    ledc_channel.gpio_num = MR_PWMB_GPIO;
    ledc_channel.channel  = LEDC_CHANNEL_1;
    ledc_channel_config(&ledc_channel);
    set_motor_pwm_dc(MR_PWMB_CHANNEL, 0.f);
    
    ledc_channel.gpio_num = ML_PWMA_GPIO;
    ledc_channel.channel  = LEDC_CHANNEL_2;
    ledc_channel_config(&ledc_channel);
    set_motor_pwm_dc(ML_PWMA_CHANNEL, 0.f);
    
    ledc_channel.gpio_num = ML_PWMB_GPIO;
    ledc_channel.channel  = LEDC_CHANNEL_3;
    ledc_channel_config(&ledc_channel);
    set_motor_pwm_dc(ML_PWMB_CHANNEL, 0.f);

    controller_output_enabled = false;

    return;
};

/// @brief sets the pwm duty cycle of a certain signal, must make sure duty is btwn 0 and 100 
static void set_motor_pwm_dc(ledc_channel_t channel, float duty)
{
    float normalized_value = duty / 100.f;
    uint32_t duty_val = (uint16_t)((1 << 12) - normalized_value * (1 << 12));

    ESP_ERROR_CHECK(ledc_set_duty(LEDC_LOW_SPEED_MODE, channel, duty_val));
    ESP_ERROR_CHECK(ledc_update_duty(LEDC_LOW_SPEED_MODE, channel));

    return;
};

void set_motor_voltage(MotorSide side, float voltage)
{
    if (voltage >= 0) {
        set_motor_dir(side, FORWARD);
    }
    else {
        set_motor_dir(side, BACKWARD);
    }

	voltage = fabsf(voltage);
    if (voltage > FF_VOLTAGE * 1600.f) {
        voltage = FF_VOLTAGE * 1600.f;
    }


    float duty_cycle = voltage / 6.f * 100.f;
    if (side == MOTOR_LEFT) {
        left_motor_voltage = voltage;
        // check to see if the current direction matches the target direction
        if(left_motor_dir_target != left_motor_dir_cur) {
            set_motor_pwm_dc(ML_PWMA_CHANNEL, 0.f);
            set_motor_pwm_dc(ML_PWMB_CHANNEL, 0.f);
            left_motor_dir_cur = left_motor_dir_target;
        } 
        // Set the correct PWM channel for direction
        if (left_motor_dir_cur == FORWARD) {
            set_motor_pwm_dc(ML_PWMA_CHANNEL, 0.f);
            set_motor_pwm_dc(ML_PWMB_CHANNEL, duty_cycle);
        } else {
            set_motor_pwm_dc(ML_PWMB_CHANNEL, 0.f);
            set_motor_pwm_dc(ML_PWMA_CHANNEL, duty_cycle);
        }
    }
    
    // Handle logic for the right motor
    else {
        right_motor_voltage = voltage;
        if(right_motor_dir_target != right_motor_dir_cur) {
            set_motor_pwm_dc(MR_PWMA_CHANNEL, 0.f);
            set_motor_pwm_dc(MR_PWMB_CHANNEL, 0.f);
            right_motor_dir_cur = right_motor_dir_target;
        } 
        // Set the correct PWM channel for direction
        if (right_motor_dir_cur == FORWARD) {
            set_motor_pwm_dc(MR_PWMA_CHANNEL, 0.f);
            set_motor_pwm_dc(MR_PWMB_CHANNEL, duty_cycle);
        } else {
            set_motor_pwm_dc(MR_PWMB_CHANNEL, 0.f);
            set_motor_pwm_dc(MR_PWMA_CHANNEL, duty_cycle);
        }
    }

    return;
};

void set_motor_dir(MotorSide side, MotorDir dir)
{
    if (side == MOTOR_RIGHT) 
        right_motor_dir_target = dir;
    else
        left_motor_dir_target = dir;
};

float left_ff_voltage(float speed) {
    static float oldSpeed = 0;
    float leftFF = speed * FF_VOLTAGE + BIAS_VOLTAGE;
    float acc = (speed - oldSpeed) * LOOP_FREQUENCY;
    oldSpeed = speed;
    float accFF = FF_ACC_VOLTAGE * acc;
    leftFF += accFF;
    return leftFF;
}

float right_ff_voltage(float speed) {
    static float oldSpeed = 0;
    float rightFF = speed * FF_VOLTAGE + BIAS_VOLTAGE;
    float acc = (speed - oldSpeed) * LOOP_FREQUENCY;
    oldSpeed = speed;
    float accFF = FF_ACC_VOLTAGE * acc;
    rightFF += accFF;
    return rightFF;
}

float forward_controller(void) 
{
    static float output_prev = 0.f;
    float increment = forward.velocity * LOOP_INTERVAL;
    fwd_error += increment - fwd_change;
    fwd_change = 0;
    // fwd_change_prev = fwd_change;
    float diff = fwd_error - fwd_error_prev;
    fwd_error_prev = fwd_error;
    float output = (FWD_KP * fwd_error + FWD_KD * diff) * 0.8f + 0.2f * output_prev;
    output_prev = output;
    
    return output;
};

float front_dist_controller(void)
{
    static float prev_error = 0.f;
    float error = (FRONT_REFERENCE - front_sensor_sum) * 0.002f;
    error += (error - prev_error) * 0.001f;
    prev_error = error;
    return error;
}

float rotation_controller(float adjustment) 
{
    static float output_prev = 0.f;
    float increment = rotation.velocity * LOOP_INTERVAL;
    // if (xSemaphoreTake(encoderCountMutex, portMAX_DELAY)) {
    rot_error += increment - enc_rot_change;
    enc_rot_change = 0;
        // xSemaphoreGive(encoderCountMutex);
    // }
    // rot_error += increment - yaw_change * 1.5;
    rot_error += adjustment;
    float diff = rot_error - rot_error_prev;
    rot_error_prev = rot_error;
    float output = (ROT_KP * rot_error + ROT_KD * diff) * 0.9f + 0.1f * output_prev;;
    return output;
};

#endif

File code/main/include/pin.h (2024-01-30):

#ifndef PIN_H
#define PIN_H

#include <stdio.h>
#include "freertos/FreeRTOS.h"
#include "freertos/task.h"
#include "driver/gpio.h"

/******************* Emitter + Receiver Pins *******************/
// Front Left IR Pins
#define FL_RECV_PIN GPIO_NUM_1
#define FL_EMIT_PIN GPIO_NUM_2

// Front Right IR Pins
#define FR_RECV_PIN GPIO_NUM_9
#define FR_EMIT_PIN GPIO_NUM_3

// Diagonal Right IR Pins
#define DL_RECV_PIN GPIO_NUM_14
#define DL_EMIT_PIN GPIO_NUM_21

// Diagonal Left IR Pins
#define DR_RECV_PIN GPIO_NUM_12
#define DR_EMIT_PIN GPIO_NUM_13

/******************* Motor PWM Pins *******************/
// Right Motor
#define MR_PWMA_PIN GPIO_NUM_38
#define MR_PWMB_PIN GPIO_NUM_8

// Left Motor
#define ML_PWMA_PIN GPIO_NUM_36
#define ML_PWMB_PIN GPIO_NUM_37

// Fan Motor
#define FAN_PWM_PIN GPIO_NUM_16

/******************* Button Pins *******************/
#define BTN1 GPIO_NUM_5
#define BTN2 GPIO_NUM_6

/******************* LED Pins *******************/
#define RED_LED GPIO_NUM_35
#define BLUE_LED GPIO_NUM_48
#define GREEN_LED GPIO_NUM_47


void initialize_emitter_output_pin(gpio_num_t gpio_num) {
    gpio_config_t io_conf = {
        .pin_bit_mask = (1ULL << gpio_num),
        .mode = GPIO_MODE_OUTPUT,
        .pull_up_en = GPIO_PULLUP_DISABLE,
        .pull_down_en = GPIO_PULLDOWN_DISABLE,
        .intr_type = GPIO_INTR_DISABLE
    };
    ESP_ERROR_CHECK(gpio_config(&io_conf));
}

#endif

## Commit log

2023-12-10 intial commit, added starting pcb files and esp32 code
    [mercury.kicad_pcb, mercury.kicad_sch]
2023-12-12 added more to pcb, esp32, gyro, usbc
    [mercury.kicad_sch]
2024-01-02 first completerouting of PCB
    [mercury.kicad_pcb, mercury.kicad_sch]
2024-01-25 completed 4 sensor pcb
    [mercury.kicad_pcb, mercury.kicad_sch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]
2024-01-30 pcb fixes and unit test code for each module of pcb
    [mercury_2ir-B_Cu.gbl, mercury_2ir-B_Mask.gbs, mercury_2ir-B_Paste.gbp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]
2024-01-31 cleaned file structure
    [main_pcb.kicad_pcb, main_pcb.kicad_sch, mercury.kicad_pcb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]
2024-01-31 added pcb schematic image
2024-01-31 Update README.md with schematic image
2024-02-12 added basic motor control profiles
2024-02-24 added basic search implementation
    [main_pcb.kicad_sch]
2024-03-01 changes to sensor tuning values for APEC
    [main_pcb.kicad_sch]
